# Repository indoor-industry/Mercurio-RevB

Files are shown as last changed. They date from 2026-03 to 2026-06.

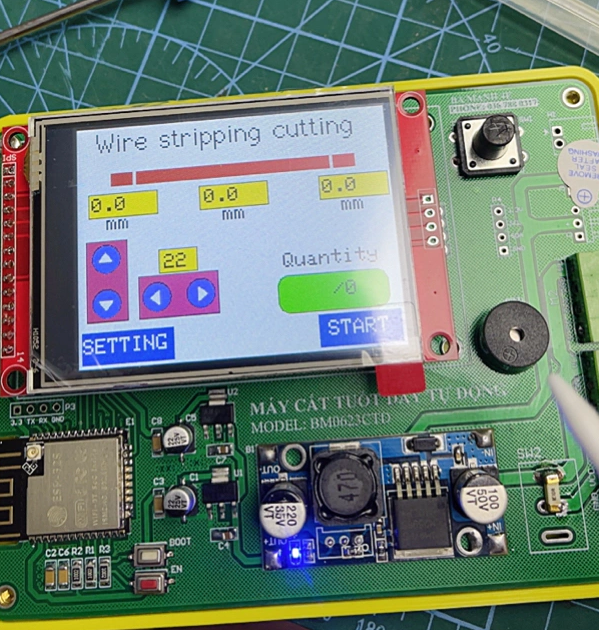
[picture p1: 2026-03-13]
Module/Case_10mm/tft-lcd-2-8-inch-ili9341-touch-320x240-1.snapshot.22/TFT LCD 2.8inch ILI9341 6.png

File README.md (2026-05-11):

Requires CDFER's KiCAD library (https://github.com/CDFER/JLCPCB-Kicad-Library) and the custom symbol and footprint libraries in Component models/KiCAD_symbol_ library. 

Contains version with bare ESP32-S3R8 chip and version with ESP32-WROOM-1 module. Only major difference is bare chip version features RTC clock and uses strapping pin GPIO46 for ILI9341 DC line. This should work but has to be tested.

## License

See the [LICENSE](LICENSE) file for details.

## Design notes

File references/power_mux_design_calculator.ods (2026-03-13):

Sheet: TPS2121
Inputs |  |  |  | Instructions:
VIN1 | 5 |  | V | Please edit green shaded cells to resemble your schematic
VIN2 | 3.7 |  | V | Grey shaded cells are automated outputs, please do not edit
R1 | 60000 | 60 | kΩ
R2 | 100000 | 100 | kΩ
R3 | 49900 | 49.9 | kΩ
R4 | 5000 | 5 | kΩ
RHYST | 10700 | 10.7 | kΩ
Overvoltage Inputs
R5 | 63400 | 63.4 | kΩ
R6 | 5000 | 5 | kΩ
R7 | 63400 | 63.4 | kΩ
R8 | 5000 | 5 | kΩ
Current Limit Inputs
RILM | 51100 | 51.1 | kΩ
Outputs
PR1 at VIN1 DC | 3.1250 |  | V
CP2 at VIN2 DC | 0.3370 |  | V |  | 0.27046783625731
IN1 at switchover | 0.5392 |  | V
Switchover using Hysteresis (N/A when not using RHYST)
PR1 R2 when IN2 selected using hysterisis | 9665.7633 |  | kΩ
PR1 when IN2 is selected using hysterisis | 0.0748 |  | V
IN1 voltage needed to switch back to IN1 when IN2 is selected using hysterisis | 2.4287 |  | V
Overvoltage
Vov1 | 14.5008 |  | V
Vov2 | 14.5008 |  | V
Current Limit
ILM | 2.20443450752477 |  | A

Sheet: TPS2116
Inputs |  |  |  | Instructions:
VIN1 | 5 |  | V | Please edit green shaded cells to resemble your schematic
VIN2 | 5 |  | V | Grey shaded cells are automated outputs, please do not edit
R1 | 9530 | 9.53 | kΩ
R2 | 5000 | 5 | kΩ
RHYST | 10000 | 10 | kΩ
Vref | 1 |  | V
Outputs
PR1 at VIN1 DC | 1.7206 |  | V
IN1 at switchover | 2.9060 |  | V
Switchover using Hysteresis (N/A when not using RHYST)
PR1 R2 when IN2 selected using hysterisis | 3333.3333 |  | kΩ
PR1 when IN2 selected using hysterisis | 0.7530 |  | V
IN1 voltage needed to switch back to IN1 when IN2 is selected using hysterisis | 3.8590 |  | V

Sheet: TPS2117
Inputs |  |  |  | Instructions:
VIN1 | 5 |  | V | Please edit green shaded cells to resemble your schematic
VIN2 | 5 |  | V | Grey shaded cells are automated outputs, please do not edit
R1 | 9530 | 9.53 | kΩ
R2 | 5000 | 5 | kΩ
RHYST | 10000 | 10 | kΩ
Vref | 1 |  | V
Outputs
PR1 at VIN1 DC | 1.7206 |  | V
IN1 at switchover | 2.9060 |  | V
Switchover using Hysteresis (N/A when not using RHYST)
PR1 R2 when IN2 selected using hysterisis | 3333.3333 |  | kΩ
PR1 when IN2 selected using hysterisis | 0.7530 |  | V
IN1 voltage needed to switch back to IN1 when IN2 is selected using hysterisis | 3.8590 |  | V

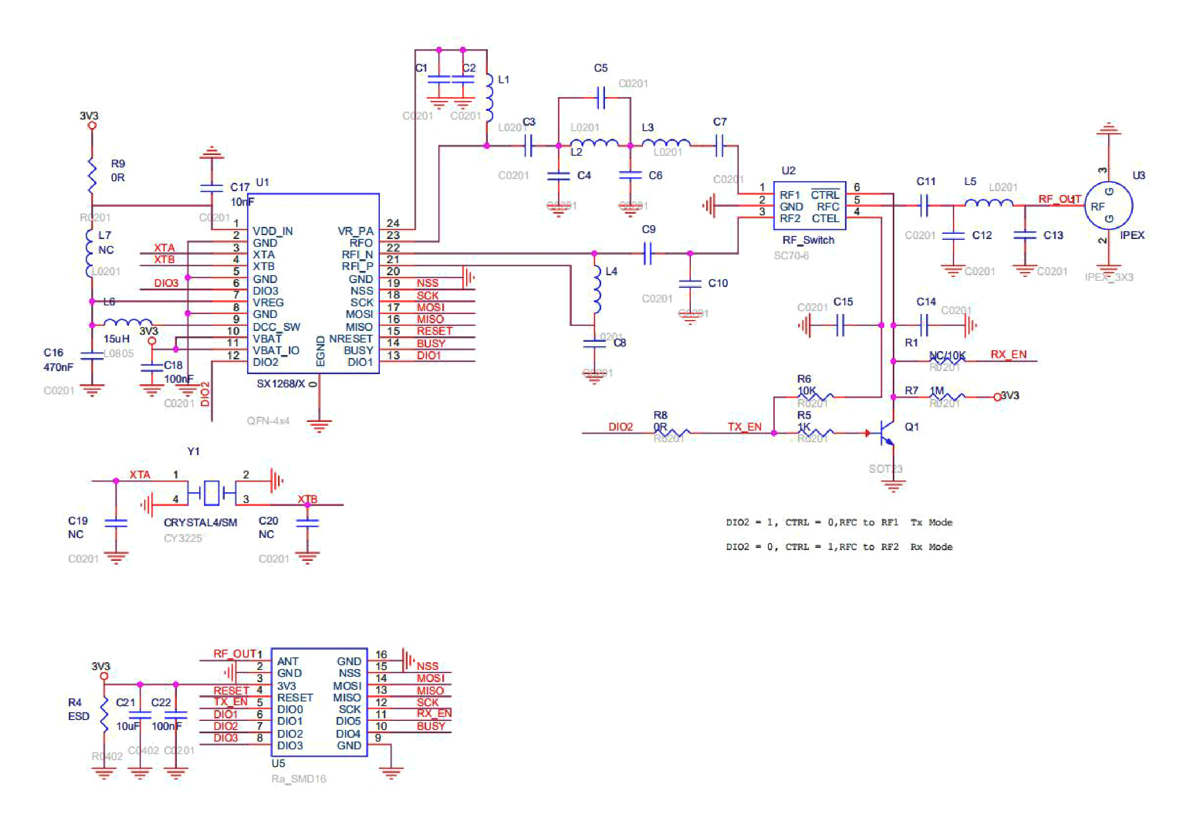
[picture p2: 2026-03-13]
references/Interfacing-RA-01-RA-02-SX1278-LoRa-Modules-with-ESP32-using-Arduino-Schematic-Diagram-CIRCUITSTATE-Electronics-01.png

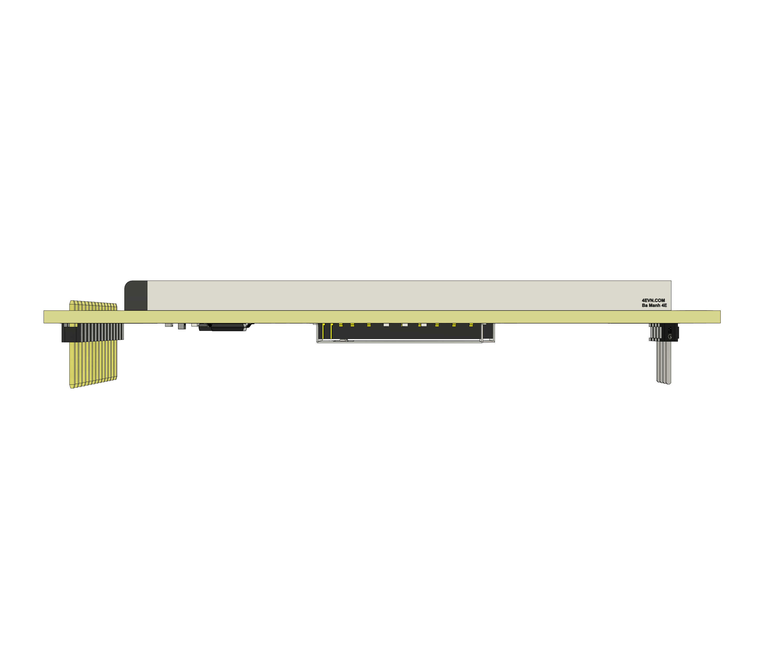
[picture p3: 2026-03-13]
Module/Case_10mm/tft-lcd-2-8-inch-ili9341-touch-320x240-1.snapshot.22/TFT LCD 2.8 inch ILI9341 4.png

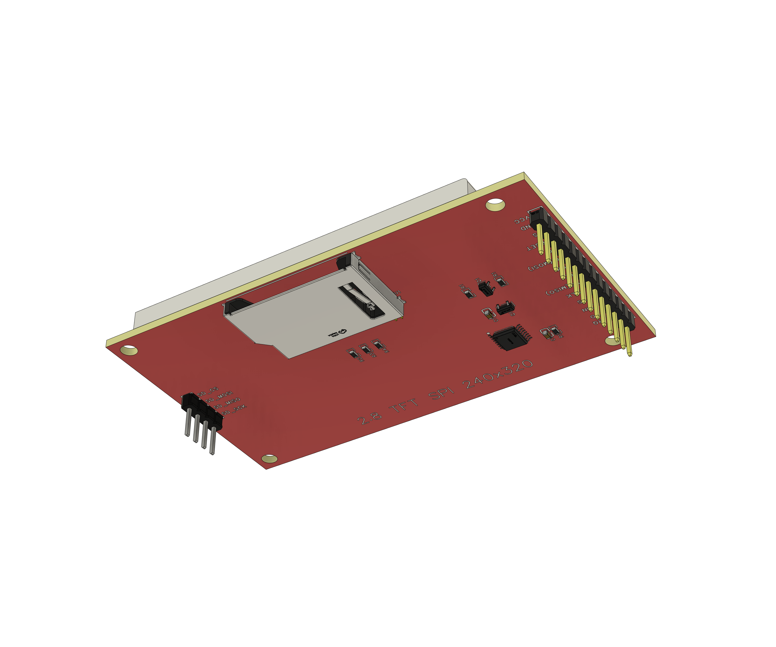
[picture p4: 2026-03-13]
Module/Case_9mm/tft-lcd-2-8-inch-ili9341-touch-320x240-1.snapshot.22/TFT LCD 2.8 inch ILI9341 3.png

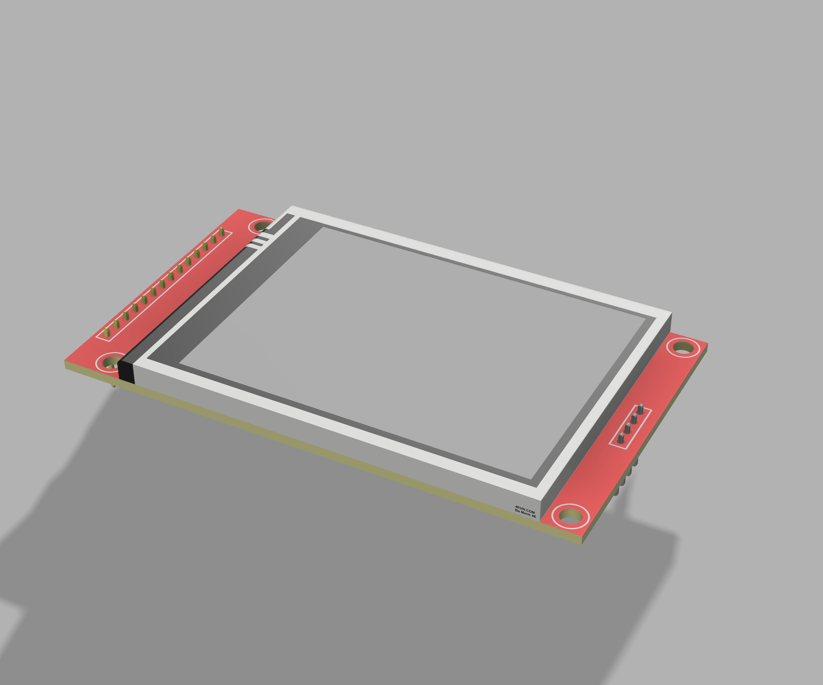
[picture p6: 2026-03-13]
Module/Case_10mm/tft-lcd-2-8-inch-ili9341-touch-320x240-1.snapshot.22/TFT LCD 2.8 inch ILI9341 5.png

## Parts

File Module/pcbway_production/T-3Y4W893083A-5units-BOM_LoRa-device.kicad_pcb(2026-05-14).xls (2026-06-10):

PCBWay Bom Quotation, Product No.:T-3Y4W893083A
Item # | *Designator | *Qty | Manufacturer | *Mfg Part # | Description / Value | Vendor Part # | *Package/Footprint | Mounting Type | Category | *Unit Price(5 units) | *Total | *Delivery Time | *Actual Purchase Mfg Part # | *PCBWay Note | Customer Reply | PCBWay Update
1 | C1 | 1 | Samsung Electro-Mechanics | CL10A225KO8NNNC | 2.2uF『 』16V 2.2uF X5R ±10% 0603 Multilayer Ceramic Capacitors MLCC - SMD/SMT ROHS『 』16V『 』±10%『 』2.2uF『 』X5R | C23630 | C_0603 | smt | Capacitors,Multilayer Ceramic Capacitors MLCC - SMD/SMT | $0.089 | $0.445
2 | C13, C20, C4, C47, C48, C7 | 6 | Samsung Electro-Mechanics | CL05A106MQ5NUNC | 10uF『 』6.3V 10uF X5R ±20% 0402 Multilayer Ceramic Capacitors MLCC - SMD/SMT ROHS『 』6.3V『 』±20%『 』10uF『 』X5R | C15525 | C_0402 | smt | Capacitors,Multilayer Ceramic Capacitors MLCC - SMD/SMT | $0.026 | $0.780
3 | C15, C16, C21, C23, C29, C30, C36, C39, C40, C46, C50, C52 | 12 | Samsung Electro-Mechanics | CL05B104KO5NNNC | 100nF『 』16V 100nF X7R ±10% 0402 Multilayer Ceramic Capacitors MLCC - SMD/SMT ROHS『 』16V『 』±10%『 』100nF『 』X7R | C1525 | C_0402 | smt | Capacitors,Multilayer Ceramic Capacitors MLCC - SMD/SMT | $0.047 | $2.820
4 | C19, C41, C42, C45, C5, C53, C57 | 7 | Samsung Electro-Mechanics | CL05A105KA5NQNC | 1uF『 』25V 1uF X5R ±10% 0402 Multilayer Ceramic Capacitors MLCC - SMD/SMT ROHS『 』25V『 』±10%『 』1uF『 』X5R | C52923 | C_0402 | smt | Capacitors,Multilayer Ceramic Capacitors MLCC - SMD/SMT | $0.015 | $0.525
5 | C2, C34, C37, C6 | 4 | Samsung Electro-Mechanics | CL10A106MA8NRNC | 10uF『 』25V 10uF X5R ±20% 0603 Multilayer Ceramic Capacitors MLCC - SMD/SMT ROHS『 』25V『 』±20%『 』10uF『 』X5R | C96446 | C_0603 | smt | Capacitors,Multilayer Ceramic Capacitors MLCC - SMD/SMT | $0.063 | $1.260
6 | C24, C9 | 2 | FH(Guangdong Fenghua Advanced Tech) | 0402CG330J500NT | 33pF『 』50V 33pF C0G ±5% 0402 Multilayer Ceramic Capacitors MLCC - SMD/SMT ROHS『 』50V『 』±5%『 』33pF『 』C0G | C1562 | C_0402 | smt | Capacitors,Multilayer Ceramic Capacitors MLCC - SMD/SMT | $0.016 | $0.160
7 | C27, C28 | 2 | FH(Guangdong Fenghua Advanced Tech) | 0402CG101J500NT | 100pF『 』50V 100pF C0G ±5% 0402 Multilayer Ceramic Capacitors MLCC - SMD/SMT ROHS『 』50V『 』±5%『 』100pF『 』C0G | C1546 | C_0402 | smt | Capacitors,Multilayer Ceramic Capacitors MLCC - SMD/SMT | $0.014 | $0.140
8 | C35 | 1 | FH(Guangdong Fenghua Advanced Tech) | 0402B102K500NT | 1nF『 』50V 1nF X7R ±10% 0402 Multilayer Ceramic Capacitors MLCC - SMD/SMT ROHS『 』50V『 』±10%『 』1nF『 』X7R | C1523 | C_0402 | smt | Capacitors,Multilayer Ceramic Capacitors MLCC - SMD/SMT | $0.033 | $0.165
9 | C43, C54 | 2 | Samsung Electro-Mechanics | CL05A475MP5NRNC | 4.7uF『 』10V 4.7uF X5R ±20% 0402 Multilayer Ceramic Capacitors MLCC - SMD/SMT ROHS『 』10V『 』±20%『 』4.7uF『 』X5R | C23733 | C_0402 | smt | Capacitors,Multilayer Ceramic Capacitors MLCC - SMD/SMT | $0.082 | $0.820
10 | C44 | 1 | FH(Guangdong Fenghua Advanced Tech) | 0402B221K500NT | 220pF『 』50V 220pF X7R ±10% 0402 Multilayer Ceramic Capacitors MLCC - SMD/SMT ROHS『 』50V『 』±10%『 』220pF『 』X7R | C1530 | C_0402 | smt | Capacitors,Multilayer Ceramic Capacitors MLCC - SMD/SMT | $0.028 | $0.140
11 | C51, C56 | 2 | Samsung Electro-Mechanics | CL10A226MQ8NRNC | 22uF『 』6.3V 22uF X5R ±20% 0603 Multilayer Ceramic Capacitors MLCC - SMD/SMT ROHS『 』6.3V『 』±20%『 』22uF『 』X5R | C59461 | C_0603 | smt | Capacitors,Multilayer Ceramic Capacitors MLCC - SMD/SMT | $0.052 | $0.520
12 | C8 | 1 | Samsung Electro-Mechanics | CL05B103KB5NNNC | 10nF『 』50V 10nF X7R ±10% 0402 Multilayer Ceramic Capacitors MLCC - SMD/SMT ROHS『 』50V『 』±10%『 』10nF『 』X7R | C15195 | C_0402 | smt | Capacitors,Multilayer Ceramic Capacitors MLCC - SMD/SMT | $0.040 | $0.200
13 | D2, D4, D5 | 3 |  | KT-0603R | LED『 』Light emitting diode | C2286 | LED_0603_1608Metric | smt |  | $0.058 | $0.870
14 | FLASH1, RESET1 | 2 | XUNPU | TS-1088-AR02016 | Tactile Button, 160gf『 』Without 50mA 4mm 100MΩ 100000 Times 12V 160gf 3mm 2mm Round Button Standing paste SPST SMD Tactile Switches ROHS | C720477 | SW_TS-1088-AR02016 | smt | Switches,Tactile Switches | $0.139 | $1.390
15 | J1 | 1 |  | TF-01A | Micro_SD_Card_Det1『 』Micro SD Card Socket with one card detection pin | C91145 | TF-SMD_TF-01A | smt |  | $0.179 | $0.895
16 | J2 | 1 |  | HC-TYPE-C-16P-3M2S | USB_C_Receptacle_USB2.0_14P『 』USB 2.0-only 14P Type-C Receptacle connector | C19274016 | USB_C_Receptacle_HCTL_HC-TYPE-C-16P-01A | smt |  | $0.182 | $0.910 |  |  | The quoted part number is [HC-TYPE-C-16P-3M2S], not [HC-TYPE-C-16P-01A] as specified in description | Correct, please refer to column “*Mfg Part #” and not to column “*Package/Footprint”
17 | J8 | 1 |  | BWU.FL-IPEX1 | U.FL『 』coaxial connector (BNC, SMA, SMB, SMC, Cinch/RCA, LEMO, ...) | C5137195 | IPEX-SMD_BWIPX-1-001E | smt |  | $0.104 | $0.520 |  |  | The quoted part number is [BWU.FL-IPEX1], not [BWIPX-1-001E] as specified in description | Correct, please refer to column “*Mfg Part #” and not to column “*Package/Footprint”
18 | L2 | 1 |  | SDCL1005C68NJTDF | 68nH『 』Inductor | C32836 | L_0402 | smt |  | $0.055 | $0.275
19 | R1, R33, R7 | 3 | UNI-ROYAL(Uniroyal Elec) | 0402WGF1003TCE | 100kΩ『 』62.5mW Thick Film Resistors 50V ±100ppm/°C ±1% 100kΩ 0402 Chip Resistor - Surface Mount ROHS『 』±1%『 』±100ppm/°C | C25741 | R_0402 | tht | Resistors,Chip Resistor - Surface Mount | $0.015 | $0.225
20 | R10, R30, R50, R54, R8 | 5 | UNI-ROYAL(Uniroyal Elec) | 0402WGF0000TCE | 0Ω『 』62.5mW Thick Film Resistors 50V ±800ppm/°C ±1% 0Ω 0402 Chip Resistor - Surface Mount ROHS『 』±1%『 』±800ppm/°C | C17168 | R_0402 | tht | Resistors,Chip Resistor - Surface Mount | $0.004 | $0.100
21 | R11, R14, R16, R17, R22, R25, R31, R37, R4, R41, R49, R52, R53, R61, R62, R63, R72 | 17 | UNI-ROYAL(Uniroyal Elec) | 0402WGF1002TCE | 10kΩ『 』62.5mW Thick Film Resistors 50V ±100ppm/°C ±1% 10kΩ 0402 Chip Resistor - Surface Mount ROHS『 』±1%『 』±100ppm/°C | C25744 | R_0402 | tht | Resistors,Chip Resistor - Surface Mount | $0.001 | $0.085
22 | R12 | 1 | UNI-ROYAL(Uniroyal Elec) | 0402WGF4700TCE | 470Ω『 』62.5mW Thick Film Resistors 50V ±100ppm/°C ±1% 470Ω 0402 Chip Resistor - Surface Mount ROHS『 』±1%『 』±100ppm/°C | C25117 | R_0402 | tht | Resistors,Chip Resistor - Surface Mount | $0.020 | $0.100
23 | R13, R42 | 2 | UNI-ROYAL(Uniroyal Elec) | 0402WGF5101TCE | 5.1kΩ『 』62.5mW Thick Film Resistors 50V ±100ppm/°C ±1% 5.1kΩ 0402 Chip Resistor - Surface Mount ROHS『 』±1%『 』±100ppm/°C | C25905 | R_0402 | tht | Resistors,Chip Resistor - Surface Mount | $0.011 | $0.110
24 | R15, R20, R34, R35, R43, R44, R45, R46, R5, R55, R56, R57, R58, R59, R60, R64, R65 | 17 | UNI-ROYAL(Uniroyal Elec) | 0402WGF330JTCE | 33Ω『 』62.5mW Thick Film Resistors 50V ±100ppm/°C ±1% 33Ω 0402 Chip Resistor - Surface Mount ROHS『 』±1%『 』±100ppm/°C | C25105 | R_0402 | tht | Resistors,Chip Resistor - Surface Mount | $0.001 | $0.085
25 | R18, R2 | 2 | UNI-ROYAL(Uniroyal Elec) | 0402WGF1001TCE | 1kΩ『 』62.5mW Thick Film Resistors 50V ±100ppm/°C ±1% 1kΩ 0402 Chip Resistor - Surface Mount ROHS『 』±1%『 』±100ppm/°C | C11702 | R_0402 | tht | Resistors,Chip Resistor - Surface Mount | $0.019 | $0.190
26 | R23, R40 | 2 | UNI-ROYAL(Uniroyal Elec) | 0402WGF4702TCE | 47kΩ『 』62.5mW Thick Film Resistors 50V ±100ppm/°C ±1% 47kΩ 0402 Chip Resistor - Surface Mount ROHS『 』±1%『 』±100ppm/°C | C25792 | R_0402 | tht | Resistors,Chip Resistor - Surface Mount | $0.019 | $0.190
27 | R32 | 1 | UNI-ROYAL(Uniroyal Elec) | 0402WGF5100TCE | 510Ω『 』62.5mW Thick Film Resistors 50V ±100ppm/°C ±1% 510Ω 0402 Chip Resistor - Surface Mount ROHS『 』±1%『 』±100ppm/°C | C25123 | R_0402 | tht | Resistors,Chip Resistor - Surface Mount | $0.032 | $0.160
28 | R38 | 1 | UNI-ROYAL(Uniroyal Elec) | 0402WGF2202TCE | 22kΩ『 』62.5mW Thick Film Resistors 50V ±100ppm/°C ±1% 22kΩ 0402 Chip Resistor - Surface Mount ROHS『 』±1%『 』±100ppm/°C | C25768 | R_0402 | tht | Resistors,Chip Resistor - Surface Mount | $0.024 | $0.120
29 | R47, R48 | 2 | UNI-ROYAL(Uniroyal Elec) | 0402WGF2201TCE | 2.2kΩ『 』62.5mW Thick Film Resistors 50V ±100ppm/°C ±1% 2.2kΩ 0402 Chip Resistor - Surface Mount ROHS『 』±1%『 』±100ppm/°C | C25879 | R_0402 | tht | Resistors,Chip Resistor - Surface Mount | $0.010 | $0.100
30 | R51 | 1 | UNI-ROYAL(Uniroyal Elec) | 0603WAF1302T5E | 13kΩ『 』100mW Thick Film Resistors 75V ±100ppm/°C ±1% 13kΩ 0603 Chip Resistor - Surface Mount ROHS『 』±1%『 』±100ppm/°C | C22797 | R_0603 | smt | Resistors,Chip Resistor - Surface Mount | $0.035 | $0.175
31 | R70, R71 | 2 | UNI-ROYAL(Uniroyal Elec) | 0402WGF1000TCE | 100Ω『 』62.5mW Thick Film Resistors 50V ±1% ±200ppm/°C 100Ω 0402 Chip Resistor - Surface Mount ROHS『 』±1%『 』±200ppm/°C | C25076 | R_0402 | tht | Resistors,Chip Resistor - Surface Mount | $0.012 | $0.120
32 | SW1, SW2 | 2 |  | EVQPUC02K | EVQPUC02K | C79174 | SW-SMD_EVQPUD02K | smt |  | $0.342 | $3.420 |  |  | The quoted part number is [EVQPUC02K], not [EVQPUD02K] as specified in description | Correct, please refer to column “*Mfg Part #” and not to column “*Package/Footprint”
33 | U10 | 1 | Torex Semicon | XC6206P332MR-G | XC6206P332MR『 』200mA Fixed 3.3V Positive electrode 6V SOT-23-3L Voltage Regulators - Linear, Low Drop Out (LDO) Regulators ROHS | C5446 | SOT-23-3_L2.9-W1.6-P1.90-LS2.8-BR | smt | Power Management ICs,Linear Voltage Regulators (LDO) | $0.291 | $1.455
34 | U12 | 1 |  | TLV62569DBVR | TLV62569DBV『 』High Efficiency Synchronous Buck Converter, Adjustable Output 0.6V-5.5V, 2A, SOT-23-5 | C141836 | SOT-23-5 | smt |  | $0.513 | $2.565 | 7-10 Workdays
35 | U14 | 1 |  | MCP23017T-E/ML | MCP23017_ML『 』16-bit I/O expander, I2C, interrupts, w pull-ups, GPA/B7 output only (https://microchip.my.site.com/s/article/GPA7---GPB7-Cannot-Be-Used-as-Inputs-In-MCP23017), QFN-28 | C629439 | QFN-28-1EP_6x6mm_P0.65mm_EP4.25x4.25mm | smt |  | $2.561 | $12.805
36 | U17 | 1 |  | Ra-01SH-P | RA-01SH-P | C42420049 | COMM-SMD_17P-L17.0-W16.0-P2.00_RA-01S-P | smt |  | $7.516 | $37.580
37 | U18 | 1 |  | L76KB-A58 | L76KB-A58 | C2916234 | GPSM-SMD_18P-L10.1-W9.7-P1.10 | smt |  | $5.735 | $28.675
38 | U19 | 1 |  | MAX98357AETE+T | MAX98357A『 』Mono DAC with amplifier, I2S, PCM, TDM, 32-bit, 96khz, 3.2W, TQFP-16 | C910544 | TQFN-16-1EP_3x3mm_P0.5mm_EP1.23x1.23mm | smt |  | $1.449 | $7.245
39 | U3 | 1 |  | ICS-43432 | ICS-43432 | C574021 | SENSOR-SMD_ICS-43432 | smt |  | $4.971 | $24.855 | 7-10 Workdays
40 | U4 | 1 |  | ESP32-S3-WROOM-1(N16R8) | ESP32-S3-WROOM-1(N16R8) | C2913202 | WIRELM-SMD_ESP32-S3-WROOM-1 | smt |  | $4.226 | $21.130 |  | ESP32-S3-WROOM-1-N16R8 |  | Correct, that seems like a matter of formatting
41 | U5 | 1 |  | SK-12D02-VG5 | SK-12D02-VG5 | C136722 | SW-TH_SK-12D02-VG5 | tht |  | $0.201 | $1.005
42 | U6 | 1 |  | USBLC6-2P6 | USBLC6-2P6『 』Very low capacitance ESD protection diode, 2 data-line, SOT-666 | C15999 | SOT-666 | smt |  | $0.212 | $1.060
43 | U7 | 1 |  | BQ25185DLHR | BQ25185DLHR | C19725033 | WSON-10_L2.2-W2.0-P0.40-BL-EP_TI_DLH0010A | smt |  | $2.325 | $11.625
44 | U8 | 1 |  | TPS22917LDBVR | TPS22917LDBV『 』1V to 5.5V, 2A, 80mΩ Ultra-Low Leakage Load Switch, Active Low, SOT23-6 | C3235537 | SOT-23-6 | smt |  | $0.560 | $2.800
45 | U9 | 1 |  | MHCI04020-2R2M-R8 | MHCI04020-2R2M-R8 | C142096 | IND-SMD_L4.6-W4.1 | smt |  | $0.280 | $1.400
 |  |  |  |  |  |  |  |  |  | Component Cost | $172.22
 |  |  |  |  |  |  |  |  |  | Assembly Cost
 |  |  |  |  |  |  |  |  |  | PCB Cost
 |  |  |  |  |  |  |  |  |  | V0 Member 0% off | $0.00
 |  |  |  |  |  |  |  |  |  | All Total 5 Units | $172.22

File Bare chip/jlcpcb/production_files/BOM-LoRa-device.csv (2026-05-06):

Comment | Designator | Footprint | LCSC | Quantity
0Ω | R10,R21,R26,R27,R28,R29,R30,R50,R54,R55,R56,R57,R58,R59,R6,R60,R65,R8,R9 | R_0402 | C17168 | 19
1.4pF | C12,C31 | C_0402 | C2181496 | 2
100kΩ | R1,R33,R7 | R_0402 | C25741 | 3
100nF | C10,C15,C16,C18,C21,C23,C29,C3,C30,C32,C33,C36,C39,C40,C46 | C_0402 | C1525 | 15
100pF | C27,C28 | C_0402 | C1546 | 2
100Ω | R24,R36 | R_0402 | C25076 | 2
10kΩ | R11,R14,R16,R17,R22,R25,R3,R31,R37,R39,R4,R41,R49,R52,R53,R61,R62,R63,R67 | R_0402 | C25744 | 19
10nF | C8 | C_0402 | C15195 | 1
10uF | C11,C13,C20,C4,C47,C48,C7 | C_0402 | C15525 | 7
10uF | C55 | C_0603 | C19702 | 1
10uF | C2,C34,C6 | C_0603 | C96446 | 3
12pF | C22,C37,C38,C49 | C_0402 | C1547 | 4
13kΩ | R51 | R_0603 | C22797 | 1
1kΩ | R18,R2 | R_0402 | C11702 | 2
1nF | C35 | C_0402 | C1523 | 1
1uF | C17,C19,C25,C26,C41,C42,C45,C5,C53 | C_0402 | C52923 | 9
2.2kΩ | R47,R48 | R_0402 | C25879 | 2
2.2uF | C1 | C_0603 | C23630 | 1
2.7nH | L6 | L_0402 | C27123 | 1
220pF | C44 | C_0402 | C1530 | 1
22kΩ | R38 | R_0402 | C25768 | 1
22uF | C56 | C_0603 | C59461 | 1
24nH | L4 | L_0402 | C74301 | 1
2nH | L3 | L_0402 | C18216 | 1
32.768 kHz | Y1 | Crystal_SMD_3215-2Pin_3.2x1.5mm | C32346 | 1
33pF | C24,C9 | C_0402 | C1562 | 2
33Ω | R15,R20,R34,R35,R43,R44,R45,R46,R5 | R_0402 | C25105 | 9
4.7uF | C43,C54 | C_0402 | C23733 | 2
40MHz(10ppm) | Y2 | Crystal_SMD_2520-4Pin_2.5x2.0mm | C5261125 | 1
470Ω | R12,R19 | R_0402 | C25117 | 2
47kΩ | R23,R40 | R_0402 | C25792 | 2
5.1kΩ | R13,R42 | R_0402 | C25905 | 2
510Ω | R32 | R_0402 | C25123 | 1
68nH | L2 | L_0402 | C32836 | 1
BQ25185DLHR | U7 | WSON-10_L2.2-W2.0-P0.40-BL-EP_TI_DLH0010A | C19725033 | 1
ESP32-S3 | U1 | QFN-56-1EP_7x7mm_P0.4mm_EP4x4mm | C2913194 | 1
EVQPUC02K | SW1,SW2 | SW-SMD_EVQPUD02K | C79174 | 2
ICS-43432 | U3 | SENSOR-SMD_ICS-43432 | C574021 | 1
L76KB-A58 | U18 | GPSM-SMD_18P-L10.1-W9.7-P1.10 | C2916234 | 1
LED | D2,D3,D4,D5 | LED_0603_1608Metric | C2286 | 4
MAX98357A | U19 | TQFN-16-1EP_3x3mm_P0.5mm_EP1.23x1.23mm | C910544 | 1
MC-121-L119 | U11 | USB-C-SMD_HANBO_MC-121-L119 | C6332278 | 1
MCP23017_ML | U14 | QFN-28-1EP_6x6mm_P0.65mm_EP4.25x4.25mm | C629439 | 1
MHCI04020-2R2M-R8 | U9 | IND-SMD_L4.6-W4.1 | C142096 | 1
Micro_SD_Card_Det1 | J1 | TF-SMD_TF-01A | C91145 | 1
RA-01SH-P | U17 | COMM-SMD_17P-L17.0-W16.0-P2.00_RA-01S-P | C42420049 | 1
SK-12D02-VG5 | U5 | SW-TH_SK-12D02-VG5 | C136722 | 1
TLV62569DBV | U12 | SOT-23-5 | C141836 | 1
TPS22917LDBV | U8 | SOT-23-6 | C3235537 | 1
Tactile Button, 160gf | FLASH1,RESET1 | SW_TS-1088-AR02016 | C720477 | 2
U.FL | J8 | IPEX-SMD_BWIPX-1-001E | C5137195 | 1
USBLC6-2P6 | U6 | SOT-666 | C15999 | 1
W25Q128JVS | U2 | SOIC-8_5.3x5.3mm_P1.27mm | C97521 | 1
XC6206P332MR | U10 | SOT-23-3_L2.9-W1.6-P1.90-LS2.8-BR | C5446 | 1
Conn_01x14_Pin | J4 | PinSocket_1x14_P2.54mm_Vertical |  | 1
Conn_01x04_Pin | J3 | PinSocket_1x04_P2.54mm_Vertical |  | 1
Conn_01x04_Pin | J6 | PinSocket_1x04_P2.54mm_Vertical |  | 1
Antenna | AE1 | Texas_SWRA117D_2.4GHz_Left |  | 1
DNP |  | C_0402 |  | 0
~ |  | C_0402 |  | 0
DNP |  | L_0402 |  | 0
~ |  | C_0402 |  | 0
~ |  | C_0402 |  | 0
~ |  | C_0402 |  | 0
TestPoint | TP1 | TestPoint_Loop_D1.80mm_Drill1.0mm_Beaded |  | 1

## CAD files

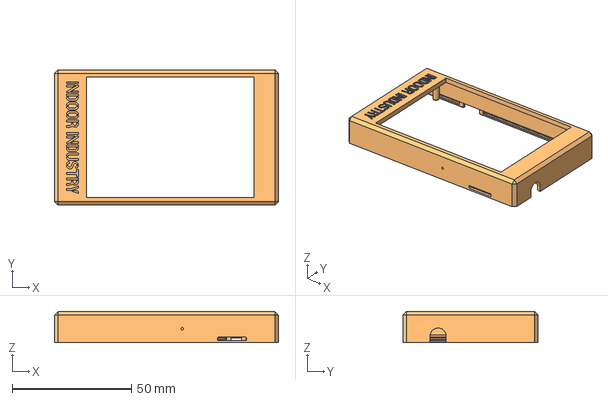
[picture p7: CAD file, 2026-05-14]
Module/Case_10mm/LoRa-device-Lid.step
94.0 x 56.8 x 13.0 mm

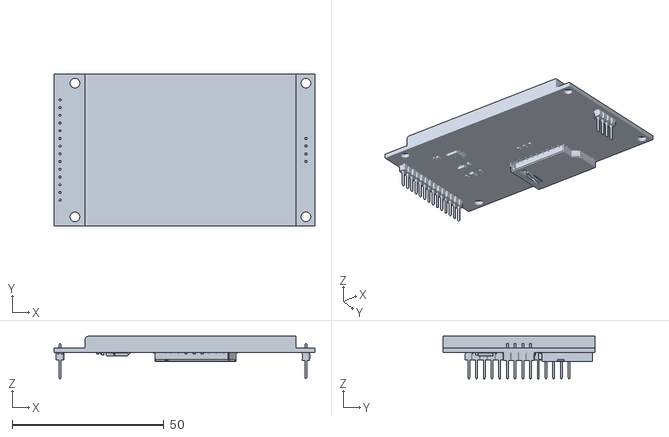
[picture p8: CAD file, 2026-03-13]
Module/Case_10mm/tft-lcd-2-8-inch-ili9341-touch-320x240-1.snapshot.22/TFT LCD 2.8 inch ILI9341.stl
86.0 x 50.0 x 14.0

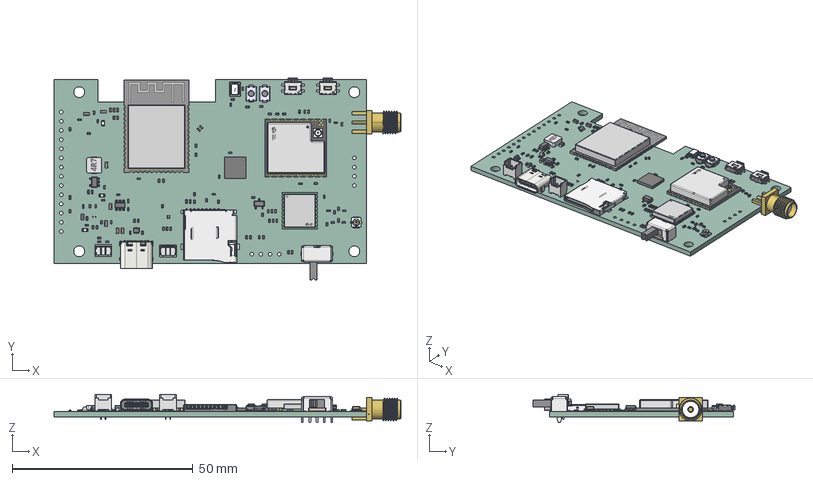
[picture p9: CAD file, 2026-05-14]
Module/Case_9mm/LoRa-device.step
96.0 x 55.8 x 7.85 mm
R_0402_1005Metric x 55
LED_0603_1608Metric x 3
C_0402_1005Metric x 38
SOT-23-5
L_0402_1005Metric
CONN-TH_1.25T-1-2A x 2
TS-1088-AR02016 x 2
SOT_666
SMA-TH_5P-L6.5-W6.5-H9.5_BWSMA-KE-P001
C_0603_1608Metric x 7
IND-SMD_L4.6-W4.1-H1.5
SOT-23-3L_L2.9-W1.6-H1.1-LS2.8-P0.95
SOT-23-6
R_0603_1608Metric
IPEX-SMD_BWIPX-1-001E
USB_C_Receptacle_16P_TopMnt_Horizontal_GCT_USB4105-xx-A
QFN-28-1EP_6x6mm_Pitch0.65mm
SW-SMD_EVQPUC02K-L4.5-W4.7-H1.7-P5.25-LS6.4 x 2
WIRELM-SMD_ESP32-S3-WROOM-1
GPSM-SMD_18P-L10.1-W9.7-P1.10
TF-SMD_TF-01A
SENSOR-SMD_ICS-43432
COMM-SMD_17P-L17.0-W16.0-P2.00_RA-01S-P
LoRa-device_PCB

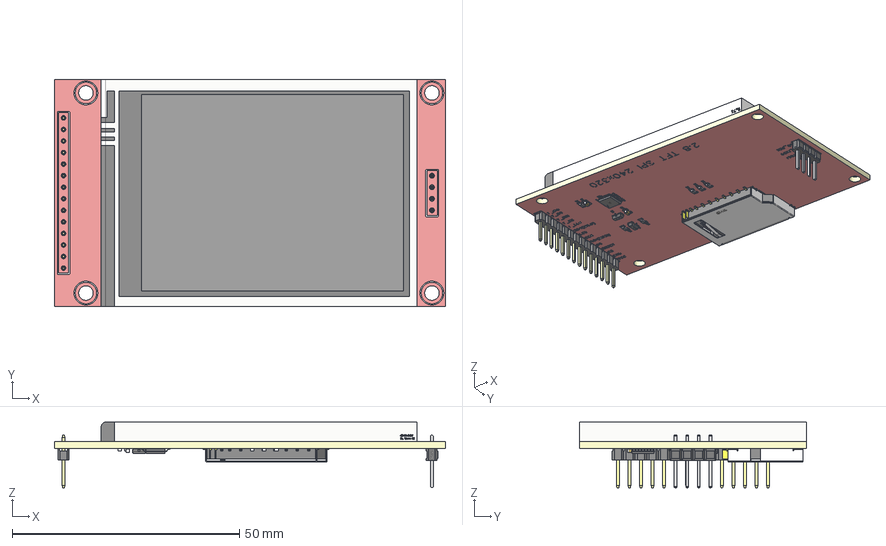
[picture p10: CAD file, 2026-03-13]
Module/Case_10mm/tft-lcd-2-8-inch-ili9341-touch-320x240-1.snapshot.22/TFT LCD 2.8 inch ILI9341 touch.step
86.0 x 50.0 x 14.5 mm
Board~s9RP
TopSilkscreen~s9RP
BottomSilkscreen~s9RP
HDR-TH_4P-P2.54-V-M~HDR-TH_4P-P2.54-M-LI-1X4P~s9RP
R0603~R0603~s9RP x 6
C0603~C0603_L1.6-W0.8-H0.8~s9RP x 2
CONN-TH_PZ254V-11-14P~CONN-TH_PZ254V-11-14P~s9RP
SD-CARD-SMD_SD-CARD-11P~SD-CARD-SMD_SD-CARD-11P~s9RP
TSSOP-16_L5.0-W4.4-P0.65-LS6.4-BL~TSSOP-16_L5.0-W4.4-H1.0-LS6.4-P0.65 ~s9RP
SOT-23-3_L2.9-W1.3-P1.90-LS2.4-BR~SOT-23-3P_L2.9-W1.3-H1.0-LS2.4-P0.9 5~s9RP x 2

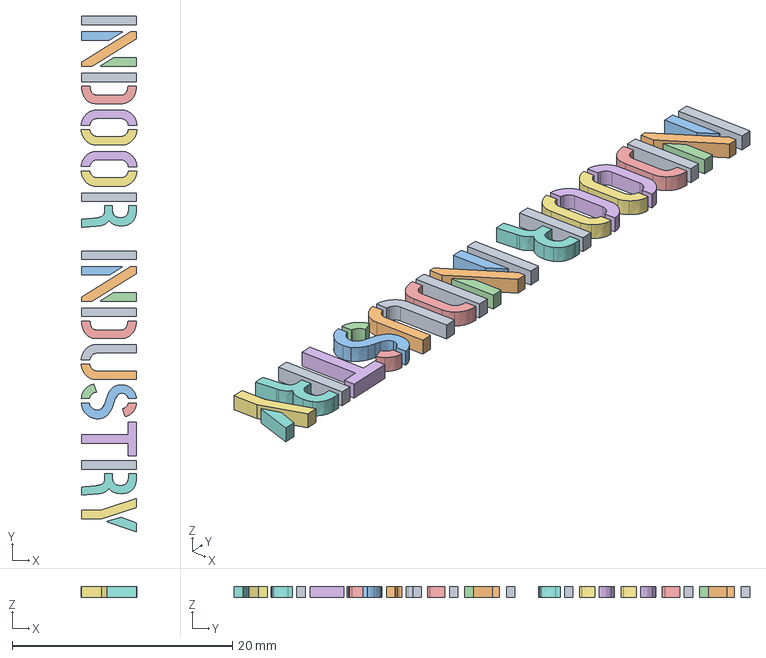
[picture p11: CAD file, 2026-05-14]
Module/Case_10mm/LoRa-device-Text.step
5.07 x 46.8 x 1.00 mm

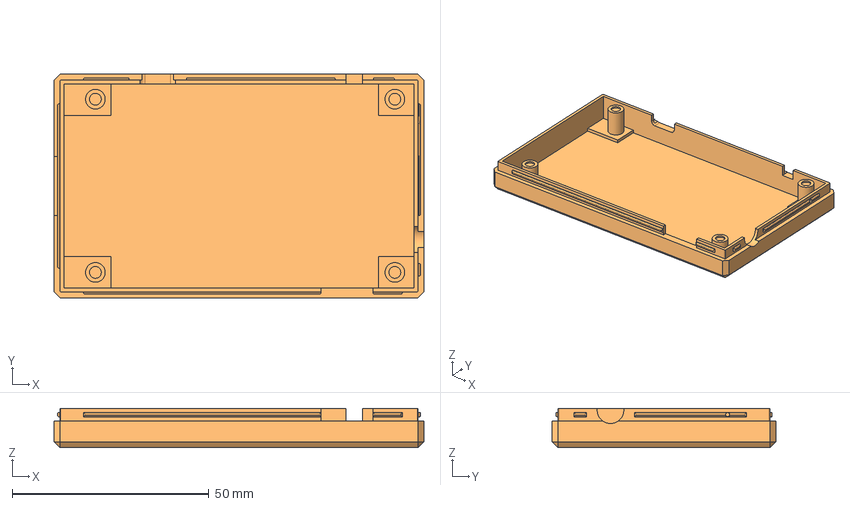
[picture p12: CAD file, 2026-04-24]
Module/Case_9mm/LoRa-device-Bottom.step
94.0 x 56.8 x 10.0 mm

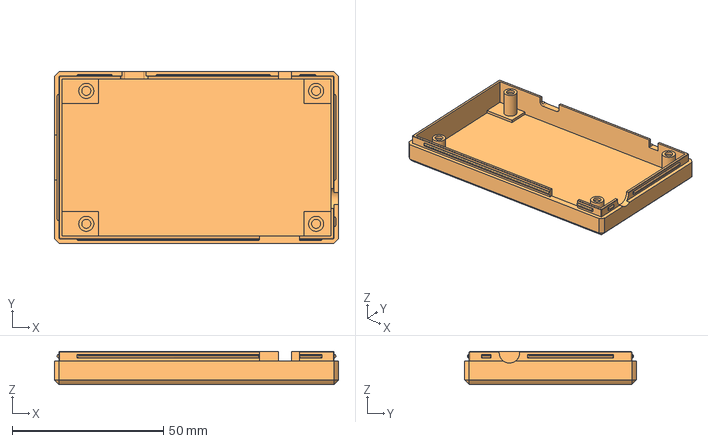
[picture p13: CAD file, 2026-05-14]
Module/Case_10mm/LoRa-device-Bottom.step
94.0 x 56.8 x 11.0 mm

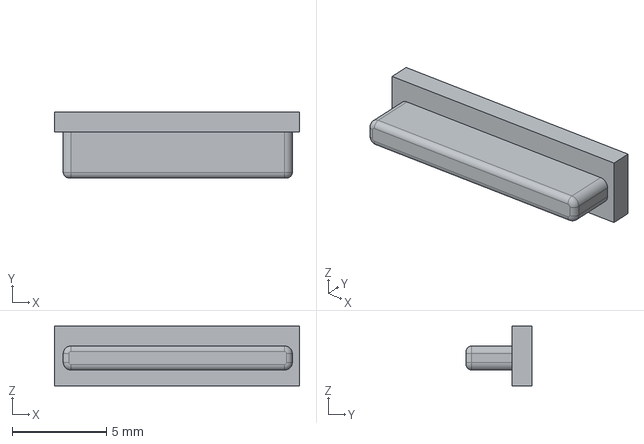
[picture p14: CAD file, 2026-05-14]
Module/Case_10mm/LoRa-device-Buttons.step
13.0 x 3.50 x 3.17 mm

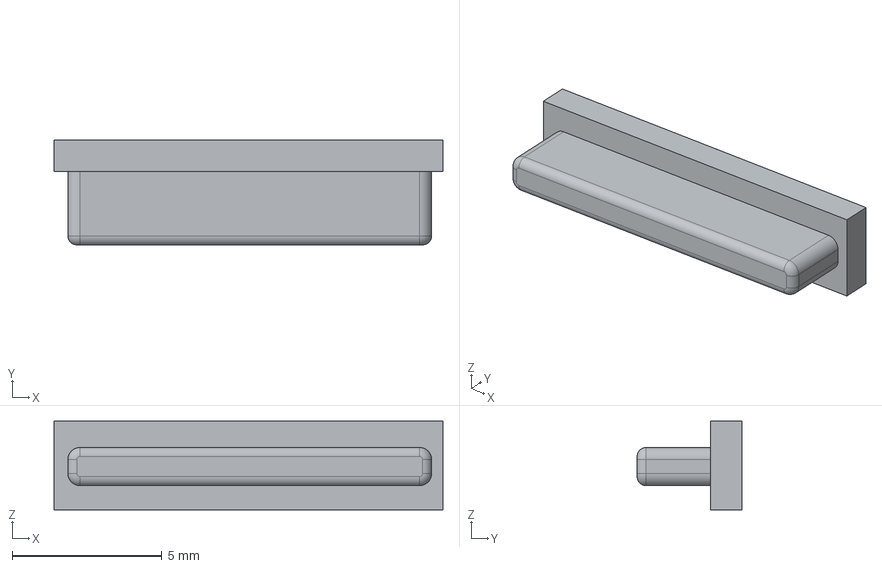
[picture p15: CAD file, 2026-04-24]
Module/Case_9mm/LoRa-device-Buttons.step
13.0 x 3.50 x 2.97 mm

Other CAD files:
Module/Case_9mm/LoRa-device-Lid.step
Module/Case_9mm/LoRa-device-Text.step
Module/Case_10mm/LoRa-device.FCStd
Module/Case_9mm/LoRa-device.FCStd

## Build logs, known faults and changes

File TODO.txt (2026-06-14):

If everything else works:

Add module to BOM and have it assembled
Consider changing MEMS mic depending on performance
Change external I2C pin header with JST connector (SM04B-SRSS-TB(LF)(SN) LCSC: C160404)
Not necessary, but could swap positive and negative in both battery and audio out connectors, matches what I have
GPS antenna silkscreen text is in wrong position
Amplifier Jumper can probably just be fixed to GND (+12dB)

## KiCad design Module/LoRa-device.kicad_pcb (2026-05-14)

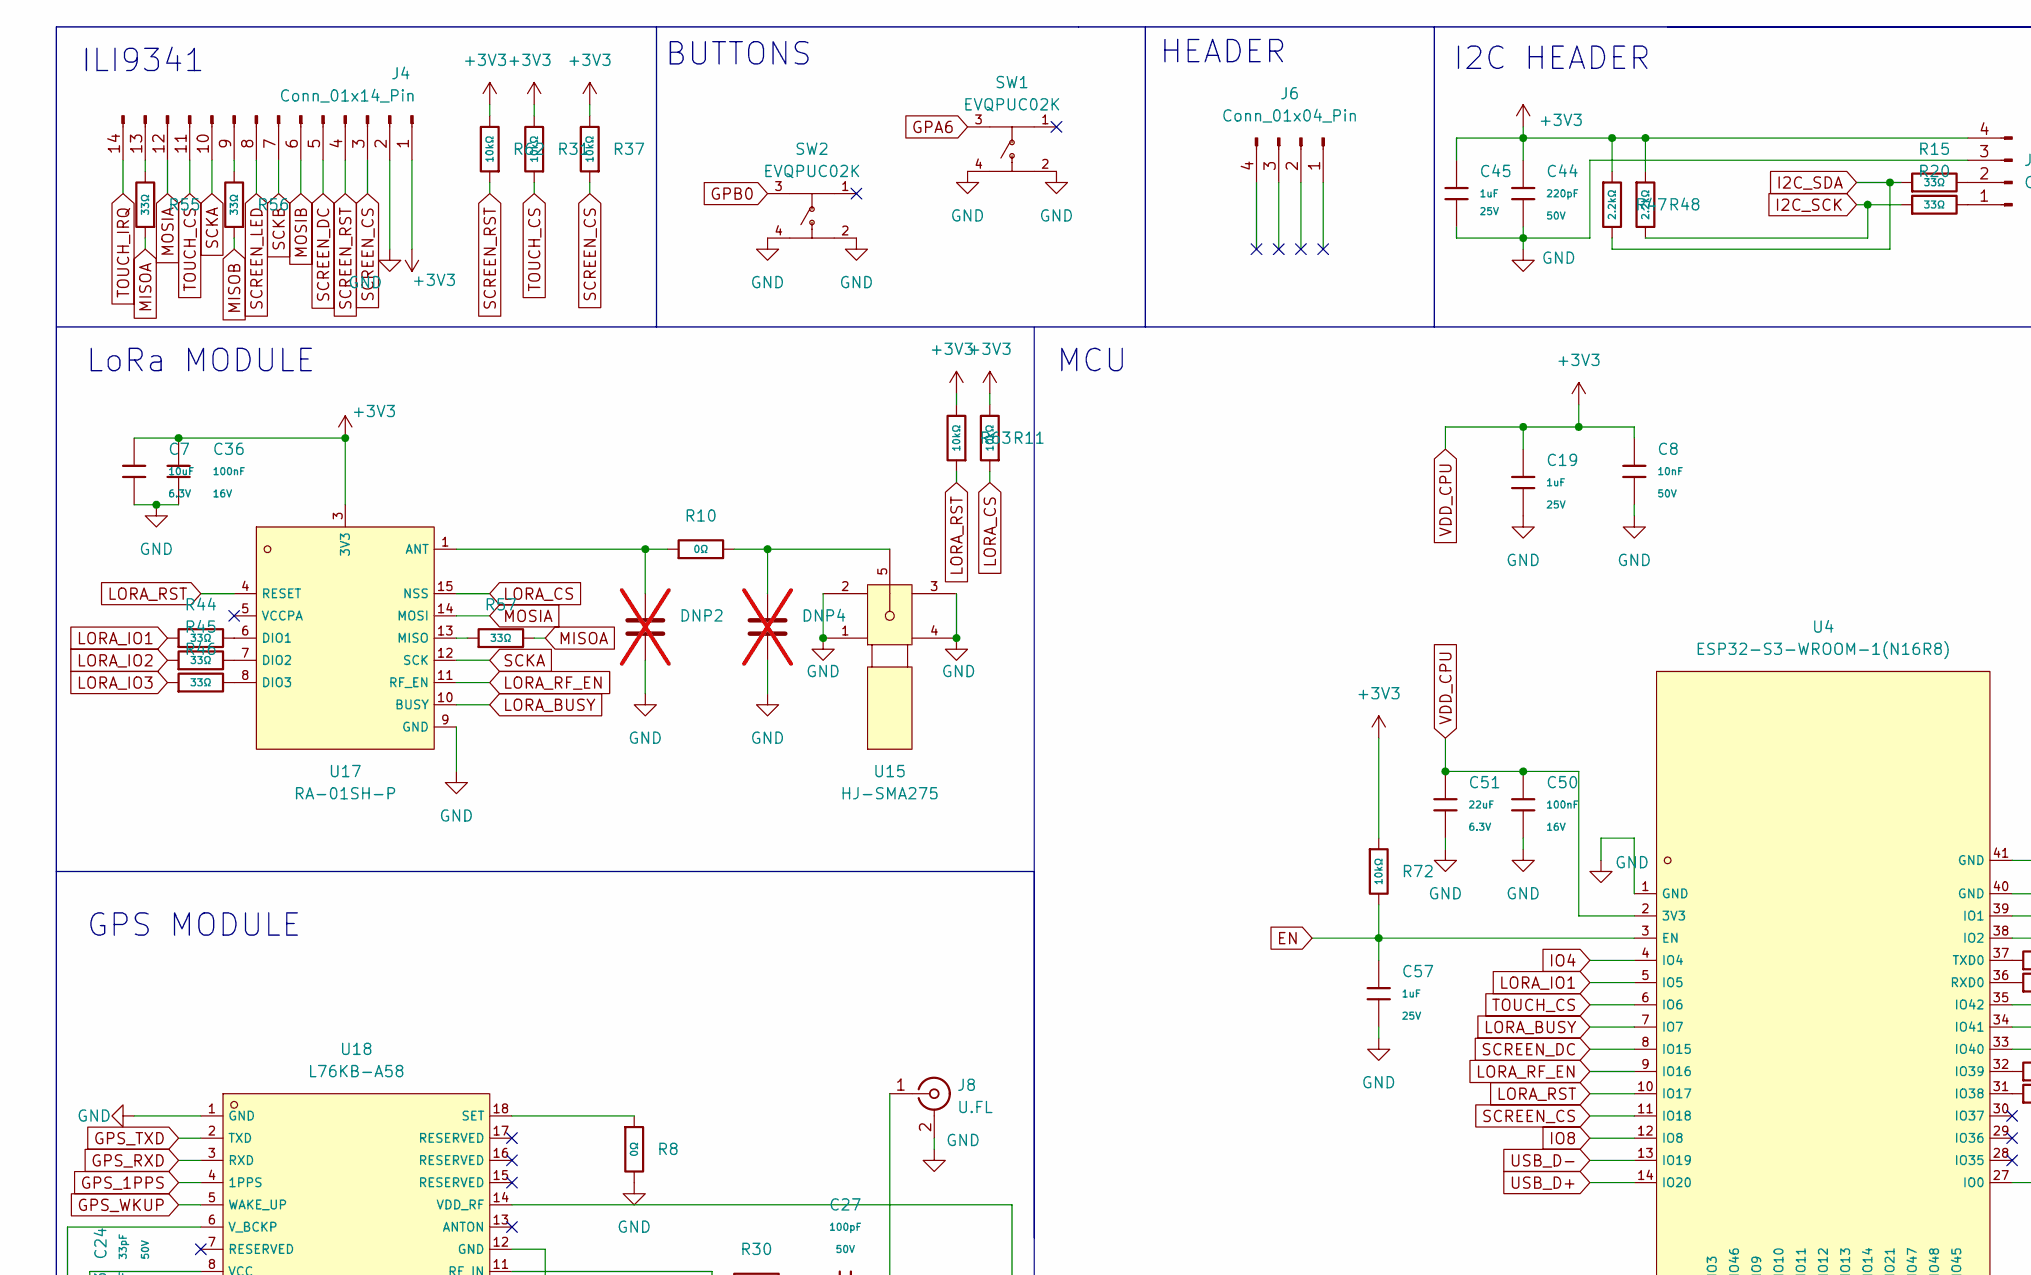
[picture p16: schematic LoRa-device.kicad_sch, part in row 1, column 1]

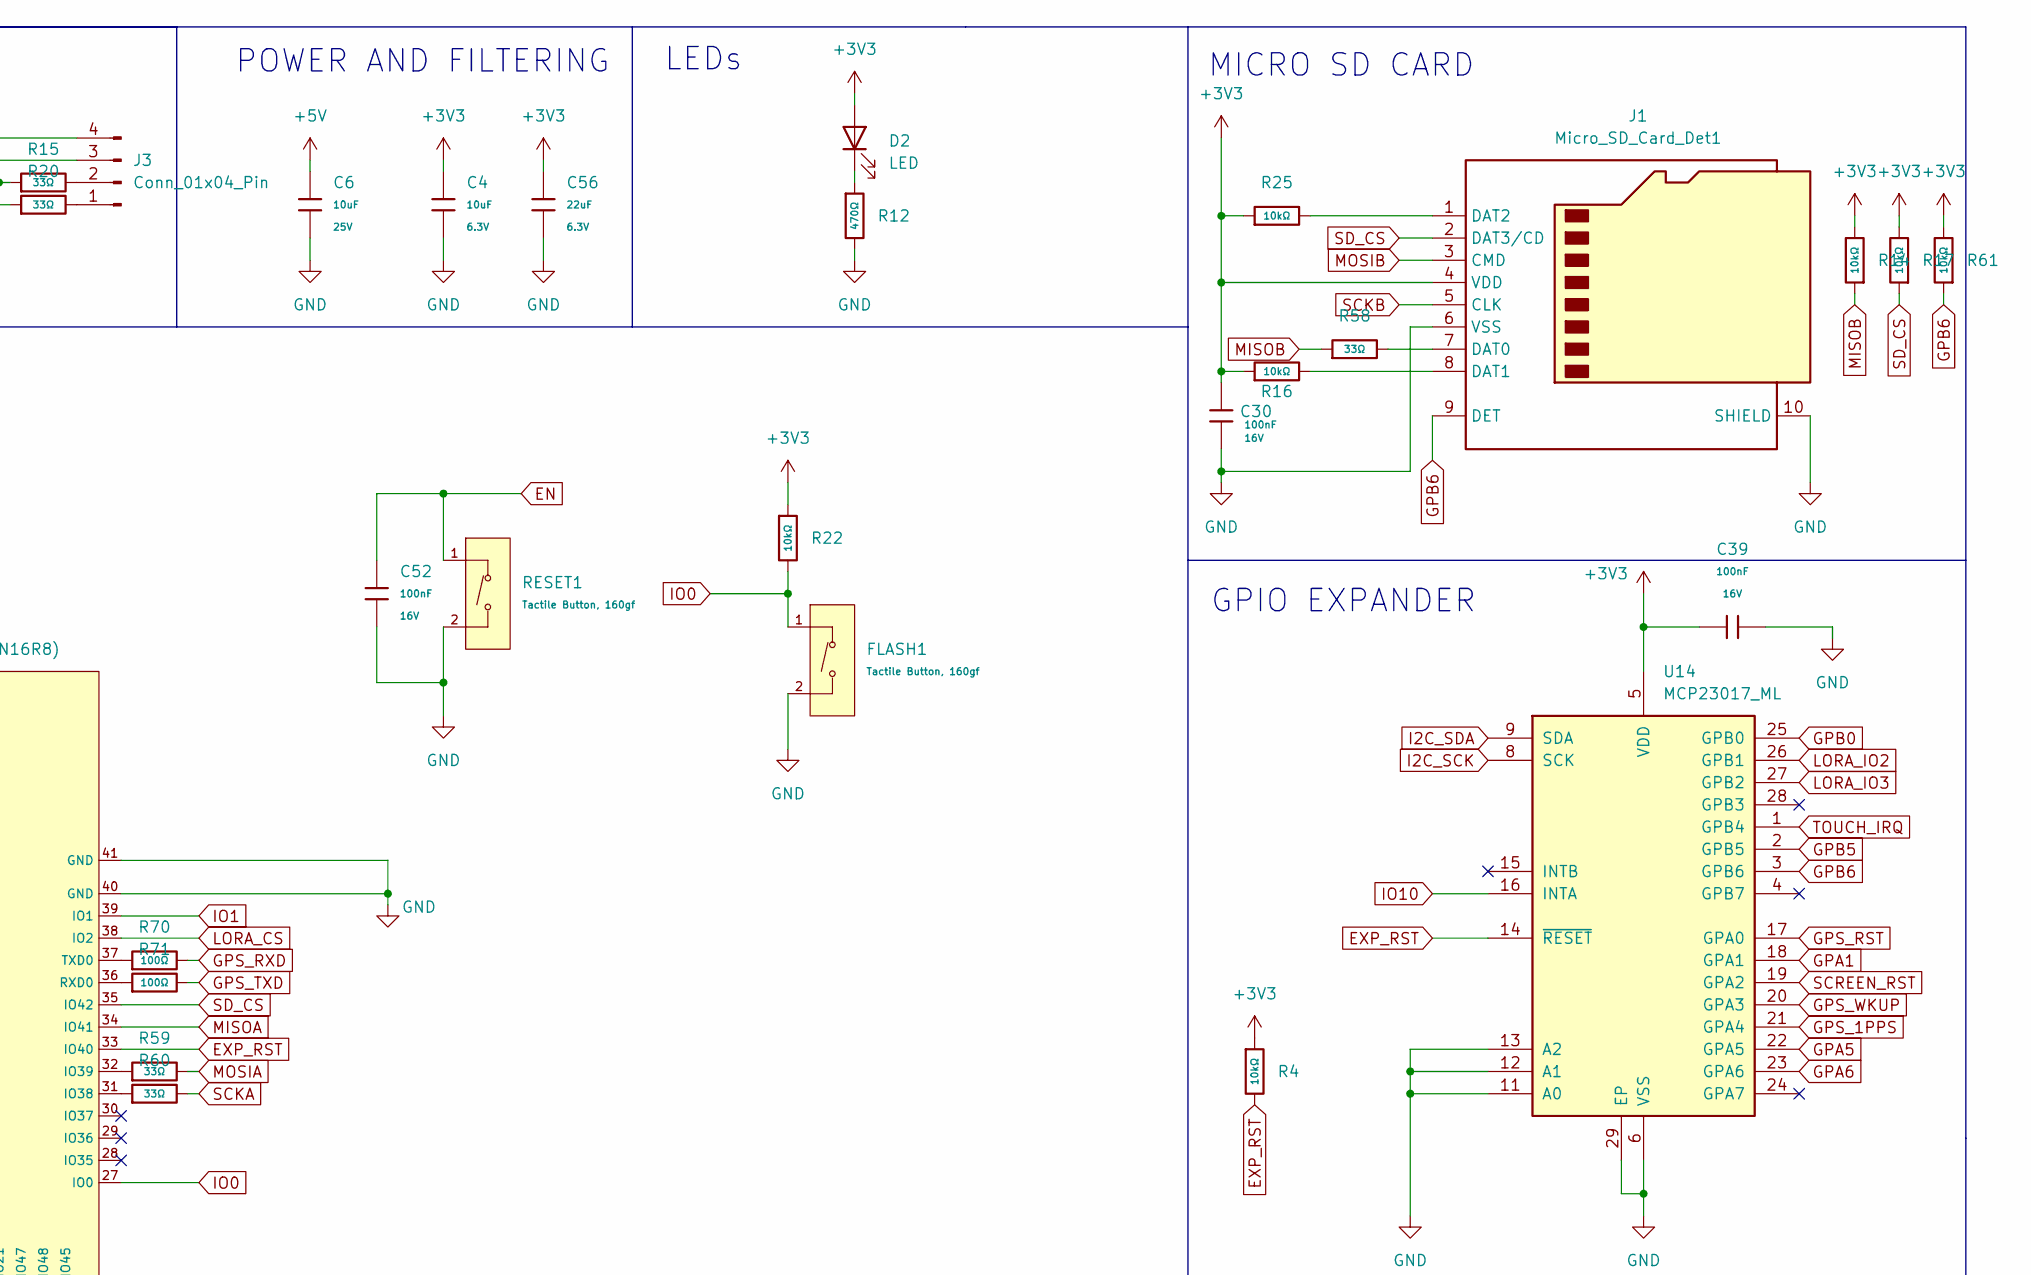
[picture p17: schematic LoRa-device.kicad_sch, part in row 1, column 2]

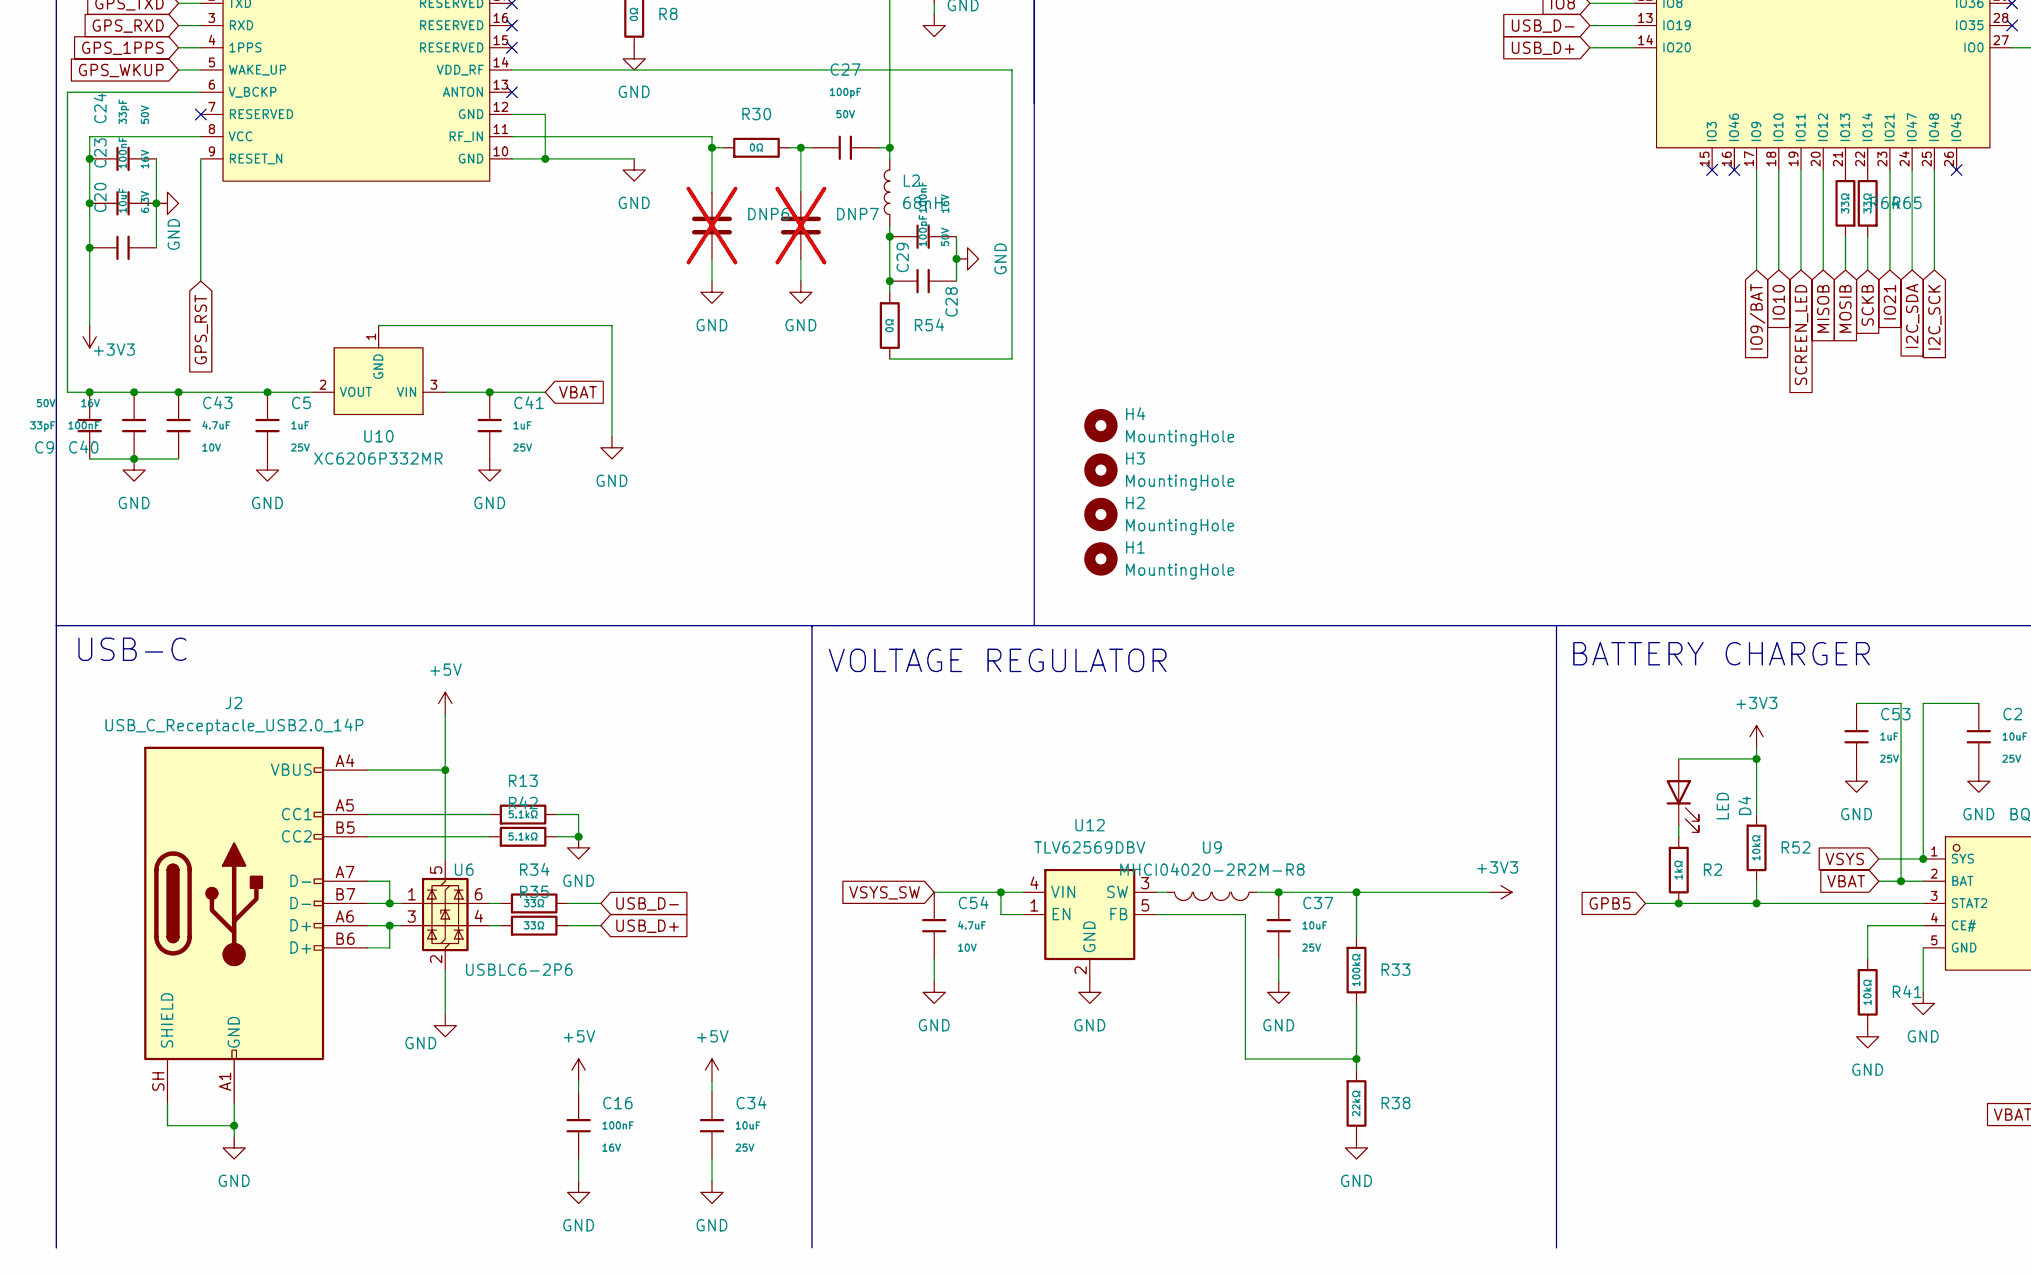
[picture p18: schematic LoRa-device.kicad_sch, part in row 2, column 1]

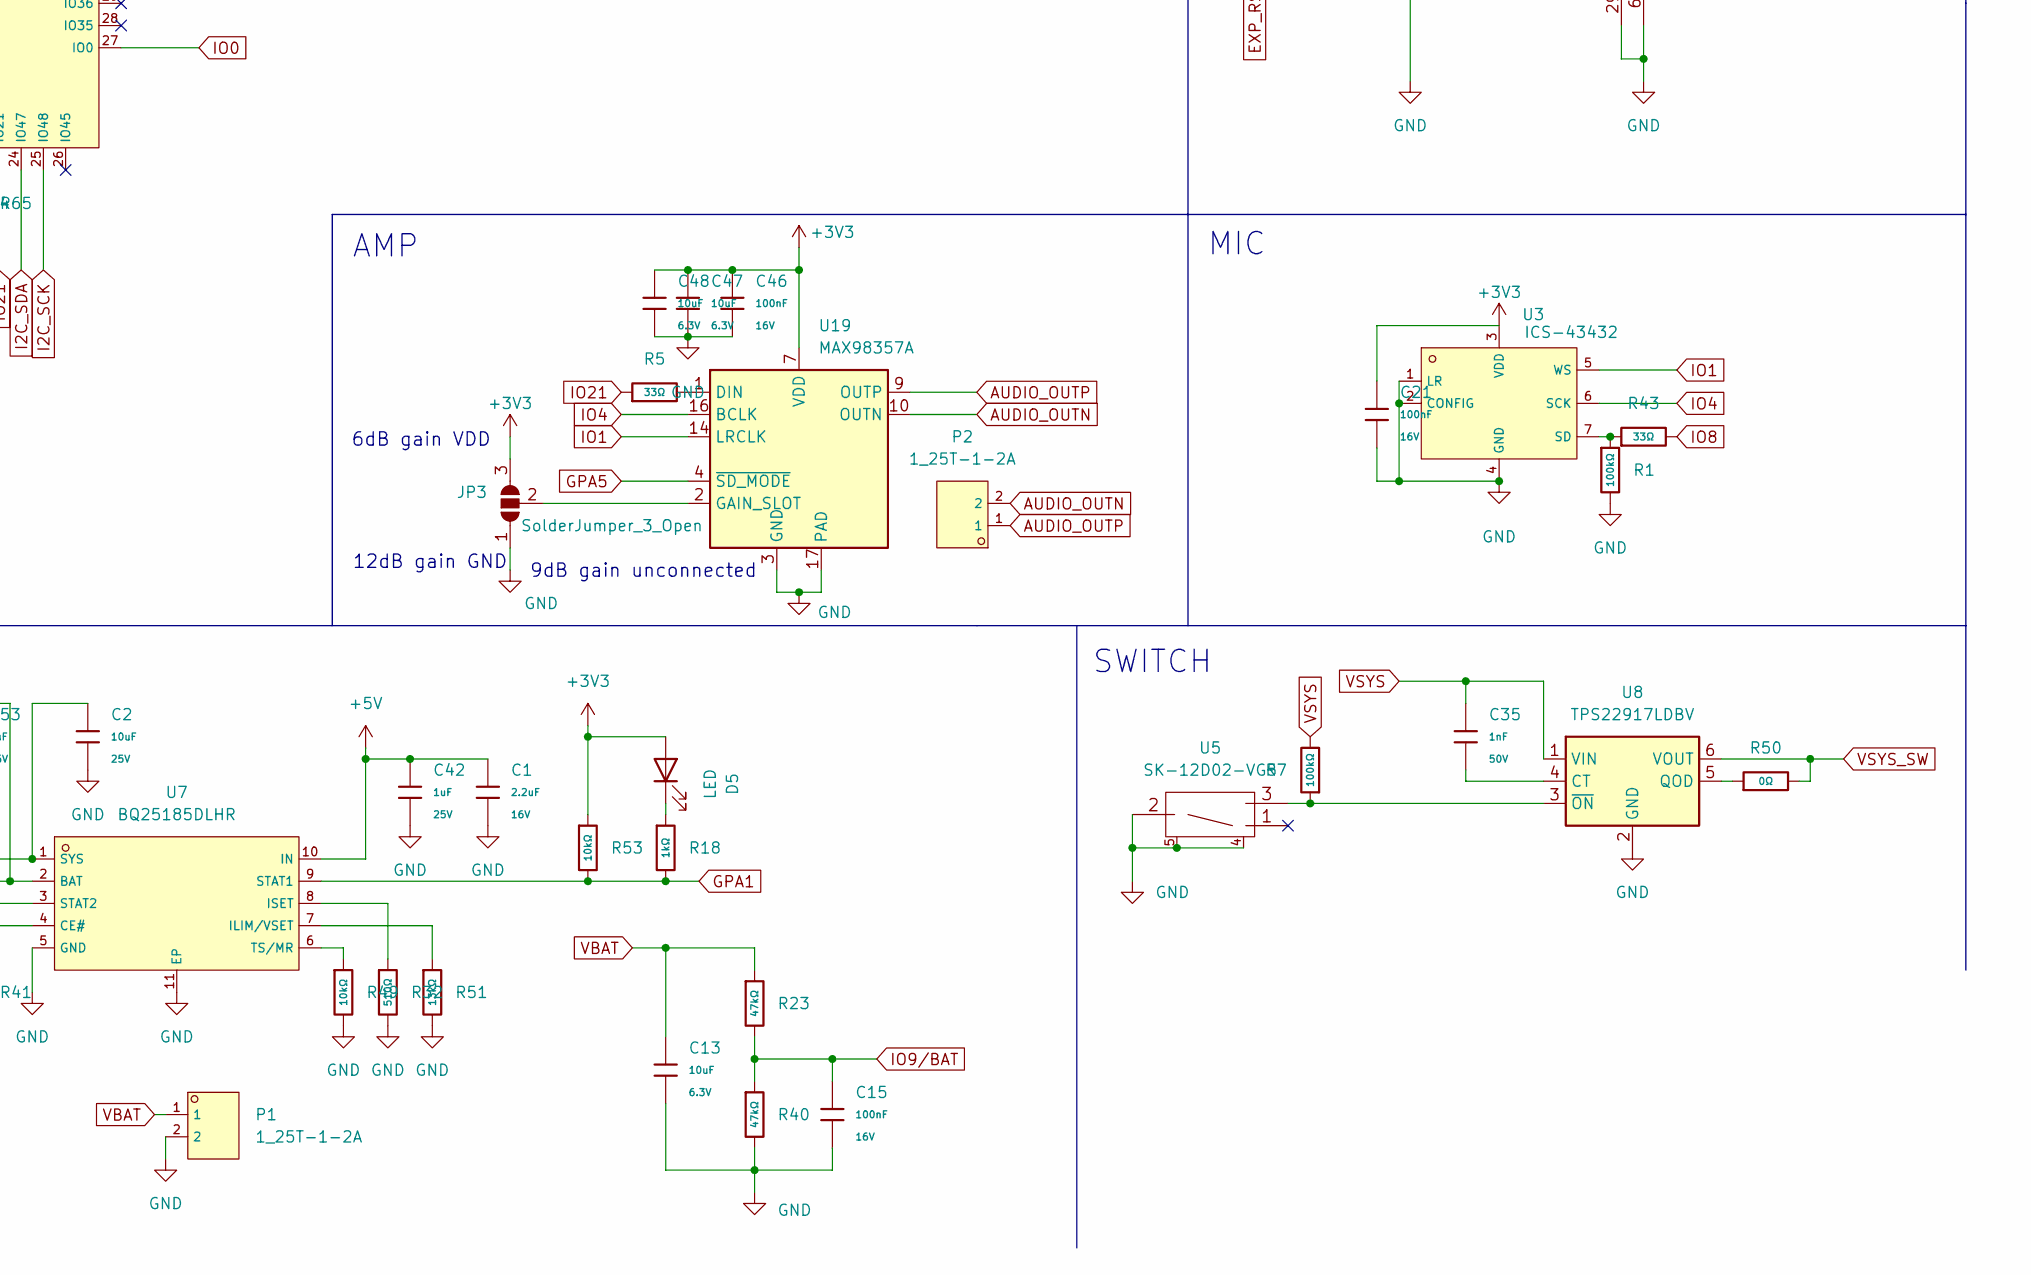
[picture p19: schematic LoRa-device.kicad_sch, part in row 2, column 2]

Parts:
C1: 2.2uF; C_0603; Voltage Rated 16V; Tolerance ±10%; Part CL10A225KO8NNNC; LCSC C23630
C2, C6, C34, C37: 10uF; C_0603; Voltage Rated 25V; Tolerance ±20%; Part CL10A106MA8NRNC; LCSC C96446
C4, C7, C13, C20, C47, C48: 10uF; C_0402; Voltage Rated 6.3V; Tolerance ±20%; Part CL05A106MQ5NUNC; LCSC C15525
C5, C19, C41, C42, C45, C53, C57: 1uF; C_0402; Voltage Rated 25V; Tolerance ±10%; Part CL05A105KA5NQNC; LCSC C52923
C8: 10nF; C_0402; Voltage Rated 50V; Tolerance ±10%; Part CL05B103KB5NNNC; LCSC C15195
C9, C24: 33pF; C_0402; Voltage Rated 50V; Tolerance ±5%; Part 0402CG330J500NT; LCSC C1562
C15, C16, C21, C23, C29, C30, C36, C39, C40, C46, C50, C52: 100nF; C_0402; Voltage Rated 16V; Tolerance ±10%; Part CL05B104KO5NNNC; LCSC C1525
C27, C28: 100pF; C_0402; Voltage Rated 50V; Tolerance ±5%; Part 0402CG101J500NT; LCSC C1546
C35: 1nF; C_0402; Voltage Rated 50V; Tolerance ±10%; Part 0402B102K500NT; LCSC C1523
C43, C54: 4.7uF; C_0402; Voltage Rated 10V; Tolerance ±20%; Part CL05A475MP5NRNC; LCSC C23733
C44: 220pF; C_0402; Voltage Rated 50V; Tolerance ±10%; Part 0402B221K500NT; LCSC C1530
C51, C56: 22uF; C_0603; Voltage Rated 6.3V; Tolerance ±20%; Part CL10A226MQ8NRNC; LCSC C59461
D2, D4, D5: LED; LED_0603_1608Metric; Part KT-0603R; LCSC C2286
DNP2, DNP4, DNP6, DNP7: C_0402; not fitted
FLASH1: Tactile Button, 160gf; SW_TS-1088-AR02016; Voltage Rating (Dc) 12V; Part TS-1088-AR02016; LCSC C720477
H1, H2, H3, H4: MountingHole; MountingHole_3mm
J1: Micro_SD_Card_Det1; TF-SMD_TF-01A; Part TF-01A; LCSC C91145
J2: USB_C_Receptacle_USB2.0_14P; USB_C_Receptacle_HCTL_HC-TYPE-C-16P-01A; Part HC-TYPE-C-16P-3M2S; LCSC C19274016
J3, J6: Conn_01x04_Pin; PinSocket_1x04_P2.54mm_Vertical
J4: Conn_01x14_Pin; PinSocket_1x14_P2.54mm_Vertical
J8: U.FL; IPEX-SMD_BWIPX-1-001E; Part BWU.FL-IPEX1; LCSC C5137195
JP3: SolderJumper_3_Open; SolderJumper-3_P1.3mm_Open_RoundedPad1.0x1.5mm
L2: 68nH; L_0402; Part SDCL1005C68NJTDF; LCSC C32836
P1, P2: 1_25T-1-2A; CONN-TH_1.25T-1-2A; LCSC C10819
R1, R7, R33: 100kΩ; R_0402; Overload Voltage (Max) 50V; Tolerance ±1%; Part 0402WGF1003TCE; LCSC C25741
R2, R18: 1kΩ; R_0402; Overload Voltage (Max) 50V; Tolerance ±1%; Part 0402WGF1001TCE; LCSC C11702
R4, R11, R14, R16, R17, R22, R25, R31, R37, R41, R49, R52, R53, R61, R62, R63, R72: 10kΩ; R_0402; Overload Voltage (Max) 50V; Tolerance ±1%; Part 0402WGF1002TCE; LCSC C25744
R5, R15, R20, R34, R35, R43, R44, R45, R46, R55, R56, R57, R58, R59, R60, R64, R65: 33Ω; R_0402; Overload Voltage (Max) 50V; Tolerance ±1%; Part 0402WGF330JTCE; LCSC C25105
R8, R10, R30, R50, R54: 0Ω; R_0402; Overload Voltage (Max) 50V; Tolerance ±1%; Part 0402WGF0000TCE; LCSC C17168
R12: 470Ω; R_0402; Overload Voltage (Max) 50V; Tolerance ±1%; Part 0402WGF4700TCE; LCSC C25117
R13, R42: 5.1kΩ; R_0402; Overload Voltage (Max) 50V; Tolerance ±1%; Part 0402WGF5101TCE; LCSC C25905
R23, R40: 47kΩ; R_0402; Overload Voltage (Max) 50V; Tolerance ±1%; Part 0402WGF4702TCE; LCSC C25792
R32: 510Ω; R_0402; Overload Voltage (Max) 50V; Tolerance ±1%; Part 0402WGF5100TCE; LCSC C25123
R38: 22kΩ; R_0402; Overload Voltage (Max) 50V; Tolerance ±1%; Part 0402WGF2202TCE; LCSC C25768
R47, R48: 2.2kΩ; R_0402; Overload Voltage (Max) 50V; Tolerance ±1%; Part 0402WGF2201TCE; LCSC C25879
R51: 13kΩ; R_0603; Overload Voltage (Max) 75V; Tolerance ±1%; Part 0603WAF1302T5E; LCSC C22797
R70, R71: 100Ω; R_0402; Overload Voltage (Max) 50V; Tolerance ±1%; Part 0402WGF1000TCE; LCSC C25076
RESET1: Tactile Button, 160gf; SW_TS-1088-AR02016; Voltage Rating (Dc) 12V; Part TS-1088-AR02016; LCSC C720477
SW1, SW2: EVQPUC02K; SW-SMD_EVQPUD02K; Part EVQPUC02K; LCSC C79174
U3: ICS-43432; SENSOR-SMD_ICS-43432; Part ICS-43432; LCSC C574021
U4: ESP32-S3-WROOM-1(N16R8); WIRELM-SMD_ESP32-S3-WROOM-1; Part ESP32-S3-WROOM-1(N16R8); LCSC C2913202
U5: SK-12D02-VG5; SW-TH_SK-12D02-VG5; Part SK-12D02-VG5; LCSC C136722
U6: USBLC6-2P6; SOT-666; Part USBLC6-2P6; LCSC C15999
U7: BQ25185DLHR; WSON-10_L2.2-W2.0-P0.40-BL-EP_TI_DLH0010A; Part BQ25185DLHR; LCSC C19725033
U8: TPS22917LDBV; SOT-23-6; Part TPS22917LDBVR; LCSC C3235537
U9: MHCI04020-2R2M-R8; IND-SMD_L4.6-W4.1; Part MHCI04020-2R2M-R8; LCSC C142096
U10: XC6206P332MR; SOT-23-3_L2.9-W1.6-P1.90-LS2.8-BR; Output Voltage 3.3V; Dropout Voltage 680mV@(100mA); Part XC6206P332MR-G; LCSC C5446
U12: TLV62569DBV; SOT-23-5; Part TLV62569DBVR; LCSC C141836
U14: MCP23017_ML; QFN-28-1EP_6x6mm_P0.65mm_EP4.25x4.25mm; Part MCP23017T-E/ML; LCSC C629439
U15: HJ-SMA275; SMA-SMD_BWSMA-KE-P001; Part HJ-SMA275; LCSC C2693809
U17: RA-01SH-P; COMM-SMD_17P-L17.0-W16.0-P2.00_RA-01S-P; Part Ra-01SH-P; LCSC C42420049
U18: L76KB-A58; GPSM-SMD_18P-L10.1-W9.7-P1.10; Part L76KB-A58; LCSC C2916234
U19: MAX98357A; TQFN-16-1EP_3x3mm_P0.5mm_EP1.23x1.23mm; Part MAX98357AETE+T; LCSC C910544

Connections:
+5V: C1.1, C6.1, C16.1, C34.1, C42.1, J2.A4 (VBUS), J2.A9 (VBUS), J2.B4 (VBUS), J2.B9 (VBUS), U6.5 (VBUS), U7.10 (IN)
AUDIO_OUTN: P2.2, U19.10 (OUTN)
AUDIO_OUTP: P2.1, U19.9 (OUTP)
EN: C52.1, C57.1, R72.2, RESET1.1 (A), U4.3 (EN)
EXP_RST: R4.2, U4.33 (IO40), U14.14 (~RESET)
GND: C1.2, C2.2, C4.2, C5.2, C6.2, C7.2, C8.2, C9.1, C13.2, C15.2, C16.2, C19.2, C20.2, C21.2, C23.2, C24.2, C28.2, C29.2, C30.2, C34.2, C36.2, C37.2, C39.1, C40.1, C41.2, C42.2, C43.2, C44.2, C45.2, C46.2, C47.2, C48.2, C50.1, C51.2, C52.2, C53.2, C54.2, C56.2, C57.2, DNP2.2, DNP4.2, DNP6.2, DNP7.2, FLASH1.2 (B), J1.6 (VSS), J1.10 (SHIELD), J1.11 (SHIELD), J1.12 (SHIELD), J1.13 (SHIELD), J2.A1 (GND), J2.A12 (GND), J2.B1 (GND), J2.B12 (GND), J2.SH (SHIELD), J3.3, J4.2, J8.2 (Ext), J8.3 (Ext), JP3.1 (A), P1.2, R1.2, R8.2, R12.2, R13.2, R32.2, R38.2, R40.2, R41.2, R42.2, R49.2, R51.2, RESET1.2 (B), SW1.2, SW1.4, SW2.2, SW2.4, U3.1 (LR), U3.2 (CONFIG), U3.4 (GND), U4.1 (GND), U4.40 (GND), U4.41 (GND), U5.2, U5.4, U5.5, U6.2 (GND), U7.5 (GND), U7.11 (EP), U8.2 (GND), U10.1 (GND), U12.2 (GND), U14.6 (VSS), U14.11 (A0), U14.12 (A1), U14.13 (A2), U14.29 (EP), U15.1, U15.2, U15.3, U15.4, U17.2 (GND), U17.9 (GND), U17.16 (GND), U17.17 (GND), U18.1 (GND), U18.10 (GND), U18.12 (GND), U19.3 (GND), U19.11 (GND), U19.15 (GND), U19.17 (PAD)
GPA1: R18.2, R53.2, U7.9 (STAT1), U14.18 (GPA1)
GPA5: U14.22 (GPA5), U19.4 (~SD_MODE)
GPA6: SW1.3, U14.23 (GPA6)
GPB0: SW2.3, U14.25 (GPB0)
GPB5: R2.2, R52.2, U7.3 (STAT2), U14.2 (GPB5)
GPB6: J1.9 (DET), R61.1, U14.3 (GPB6)
GPS_1PPS: U14.21 (GPA4), U18.4 (1PPS)
GPS_RST: U14.17 (GPA0), U18.9 (RESET_N)
GPS_RXD: R70.2, U18.3 (RXD)
GPS_TXD: R71.2, U18.2 (TXD)
GPS_WKUP: U14.20 (GPA3), U18.5 (WAKE_UP)
I2C_SCK: R20.1, R48.2, U4.25 (IO48), U14.8 (SCK)
I2C_SDA: R15.1, R47.2, U4.24 (IO47), U14.9 (SDA)
IO0: FLASH1.1 (A), R22.2, U4.27 (IO0)
IO1: U3.5 (WS), U4.39 (IO1), U19.14 (LRCLK)
IO4: U3.6 (SCK), U4.4 (IO4), U19.16 (BCLK)
IO8: R43.2, U4.12 (IO8)
IO9/BAT: C15.1, R23.2, R40.1, U4.17 (IO9)
IO10: U4.18 (IO10), U14.16 (INTA)
IO21: R5.1, U4.23 (IO21)
LORA_BUSY: U4.7 (IO7), U17.10 (BUSY)
LORA_CS: R11.1, U4.38 (IO2), U17.15 (NSS)
LORA_IO1: R44.1, U4.5 (IO5)
LORA_IO2: R45.1, U14.26 (GPB1)
LORA_IO3: R46.1, U14.27 (GPB2)
LORA_RF_EN: U4.9 (IO16), U17.11 (RF_EN)
LORA_RST: R63.1, U4.10 (IO17), U17.4 (RESET)
MISOA: R55.1, R57.2, U4.34 (IO41)
MISOB: R14.1, R56.1, R58.1, U4.20 (IO12)
MOSIA: J4.12, R59.2, U17.14 (MOSI)
MOSIB: J1.3 (CMD), J4.6, R64.1
unnamed: C27.1, DNP7.1, R30.2
unnamed: C28.1, C29.1, L2.1, R54.1
unnamed: D2.1 (K), R12.1
unnamed: D4.1 (K), R2.1
unnamed: D5.1 (K), R18.1
unnamed: DNP4.1, R10.2, U15.5
unnamed: J1.7 (DAT0), R58.2
unnamed: J1.8 (DAT1), R16.2
unnamed: J1.1 (DAT2), R25.2
unnamed: J2.A5 (CC1), R13.1
unnamed: J2.B5 (CC2), R42.1
unnamed: J2.A6 (D+), J2.B6 (D+), U6.3 (I/O2)
unnamed: J2.A7 (D-), J2.B7 (D-), U6.1 (I/O1)
unnamed: J3.1, R20.2
unnamed: J3.2, R15.2
unnamed: J4.9, R56.2
unnamed: J4.13, R55.2
unnamed: C27.2, J8.1 (In), L2.2
unnamed: JP3.2 (C), U19.2 (GAIN_SLOT)
unnamed: R34.1, U6.6 (I/O1)
unnamed: R35.1, U6.4 (I/O2)
unnamed: R1.1, R43.1, U3.7 (SD)
unnamed: R64.2, U4.21 (IO13)
unnamed: R65.2, U4.22 (IO14)
unnamed: R60.1, U4.31 (IO38)
unnamed: R59.1, U4.32 (IO39)
unnamed: R71.1, U4.36 (RXD0)
unnamed: R70.1, U4.37 (TXD0)
unnamed: R41.1, U7.4 (CE#)
unnamed: R51.1, U7.7 (ILIM/VSET)
unnamed: R32.1, U7.8 (ISET)
unnamed: R49.1, U7.6 (TS/MR)
unnamed: C35.2, U8.4 (CT)
unnamed: R50.1, U8.5 (QOD)
unnamed: R7.1, U5.3, U8.3 (~ON)
unnamed: C5.1, C9.2, C40.2, C43.1, U10.2 (VOUT), U18.6 (V_BCKP)
unnamed: R33.2, R38.1, U12.5 (FB)
unnamed: U9.1, U12.3 (SW)
unnamed: DNP2.1, R10.1, U17.1 (ANT)
unnamed: R44.2, U17.6 (DIO1)
unnamed: R45.2, U17.7 (DIO2)
unnamed: R46.2, U17.8 (DIO3)
unnamed: R57.1, U17.13 (MISO)
unnamed: DNP6.1, R30.1, U18.11 (RF_IN)
unnamed: R8.1, U18.18 (SET)
unnamed: R54.2, U18.14 (VDD_RF)
unnamed: R5.2, U19.1 (DIN)
SCKA: J4.10, R60.2, U17.12 (SCK)
SCKB: J1.5 (CLK), J4.7, R65.1
SCREEN_CS: J4.3, R37.1, U4.11 (IO18)
SCREEN_DC: J4.5, U4.8 (IO15)
SCREEN_LED: J4.8, U4.19 (IO11)
SCREEN_RST: J4.4, R62.1, U14.19 (GPA2)
SD_CS: J1.2 (DAT3/CD), R17.1, U4.35 (IO42)
TOUCH_CS: J4.11, R31.1, U4.6 (IO6)
TOUCH_IRQ: J4.14, U14.1 (GPB4)
USB_D+: R35.2, U4.14 (IO20)
USB_D-: R34.2, U4.13 (IO19)
VBAT: C13.1, C41.1, C53.1, P1.1, R23.1, U7.2 (BAT), U10.3 (VIN)
VDD_CPU: C4.1, C7.1, C8.1, C19.1, C20.1, C21.1, C23.1, C24.1, C30.1, C36.1, C37.1, C39.2, C44.1, C45.1, C46.1, C47.1, C48.1, C50.2, C51.1, C56.1, D2.2 (A), D4.2 (A), D5.2 (A), J1.4 (VDD), J3.4, J4.1, JP3.3 (B), R4.1, R11.2, R14.2, R16.1, R17.2, R22.1, R25.1, R31.2, R33.1, R37.2, R47.1, R48.1, R52.1, R53.1, R61.2, R62.2, R63.2, R72.1, U3.3 (VDD), U4.2 (3V3), U9.2, U14.5 (VDD), U17.3 (3V3), U18.8 (VCC), U19.7 (VDD), U19.8 (VDD)
VSYS: C2.1, C35.1, R7.2, U7.1 (SYS), U8.1 (VIN)
VSYS_SW: C54.1, R50.2, U8.6 (VOUT), U12.1 (EN), U12.4 (VIN)

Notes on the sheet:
BATTERY CHARGER
VOLTAGE REGULATOR
MIC
LoRa MODULE
LEDs
MCU
HEADER
MICRO SD CARD
GPS MODULE
AMP
I2C HEADER
ILI9341
9dB gain unconnected
SWITCH
12dB gain GND
6dB gain VDD
POWER AND FILTERING
BUTTONS
USB-C
GPIO EXPANDER

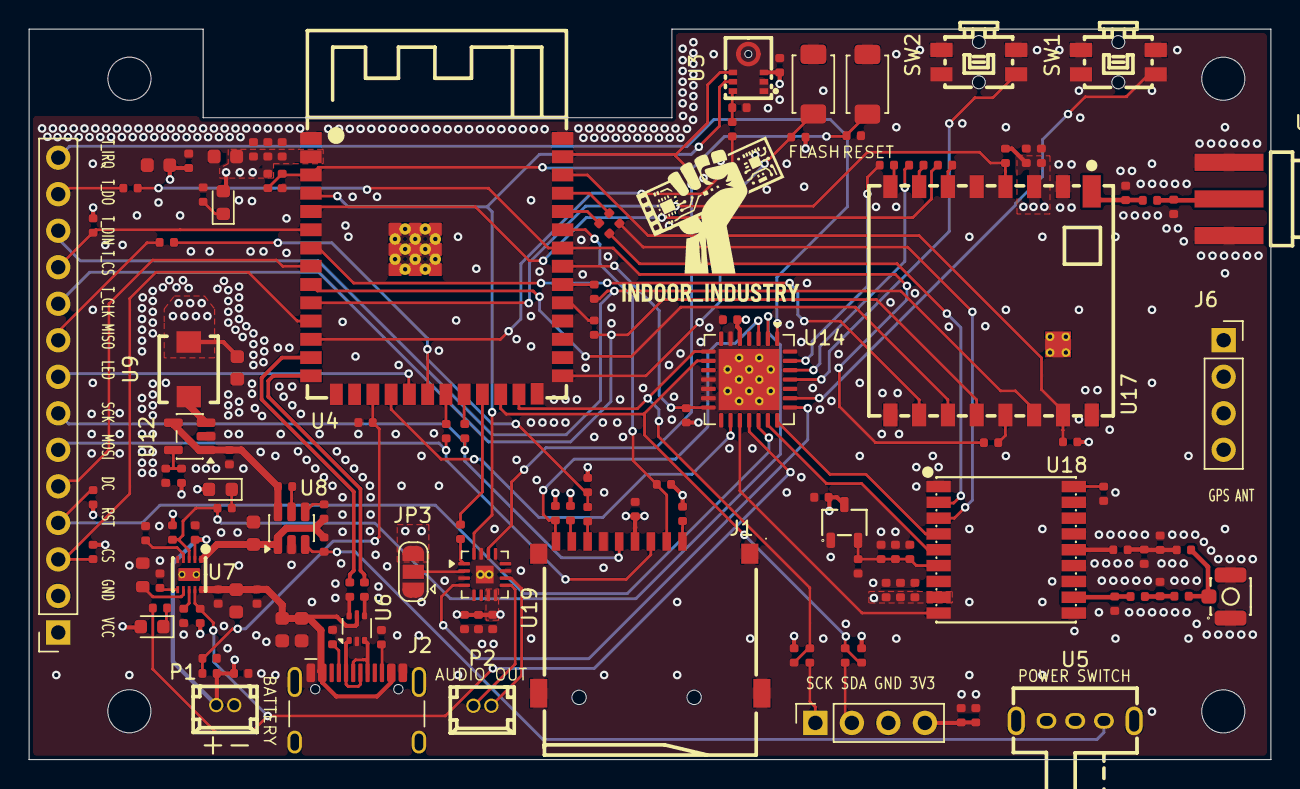
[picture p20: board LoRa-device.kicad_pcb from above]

Board: 4 copper layers, 86.4 x 50.8 mm, 136 parts (0 on the bottom side), 99 nets.

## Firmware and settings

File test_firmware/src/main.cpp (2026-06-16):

#include <Arduino.h>
#include <Wire.h>
#include <SPI.h>

#include "pins.h"
#include "config.h"
#include "mcp23017.h"
#include "display.h"
#include "touch.h"
#include "calibration.h"
#include "menu.h"
#include "board.h"
#include "test_sysinfo.h"
#include "test_battery.h"
#include "test_expander.h"
#include "test_touch.h"
#include "test_lora.h"
#include "test_sdcard.h"
#include "test_gps.h"
#include "test_audio_mic.h"
#include "test_audio_speaker.h"
#include "test_wifi_ble.h"
#include "test_backlight.h"
#include "test_calibration.h"
#include "volume.h"

MCP23017 mcp(Wire, MCP_I2C_ADDR);
unsigned long g_gpsBootMs = 0;

void setup() {
    Serial.begin(115200);
    Serial.println("[boot] LoRa test firmware starting");

    // Bring the MCP23017 out of its hardware reset before talking to it.
    pinMode(PIN_MCP_RST, OUTPUT);
    digitalWrite(PIN_MCP_RST, LOW);
    delay(10);
    digitalWrite(PIN_MCP_RST, HIGH);
    delay(10);

    Wire.begin(PIN_I2C_SDA, PIN_I2C_SCL);
    Wire.setClock(I2C_FREQ);
    if (!mcp.begin()) {
        Serial.println("WARNING: MCP23017 not responding on I2C bus");
    }

    Display::begin(mcp);
    Volume::begin();

    // SPI-A (touch + LoRa) on the global SPI object; the display/SD bus
    // has its own dedicated SPI host (see USE_HSPI_PORT in platformio.ini).
    SPI.begin(PIN_SPIA_SCLK, PIN_SPIA_MISO, PIN_SPIA_MOSI, -1);
    Touch::begin();

    // Holding SW1 during reset forces a fresh calibration even if valid
    // data is already stored in NVS - this is the escape hatch for when
    // stored calibration is bad and touch can't reach the menu's
    // "Recalibrate Touch" entry.
    bool forceCalib = !MCP23017::gpioBit(mcp.readGPIO(), MCP_BIT_SW1);
    if (!Calibration::load() || forceCalib) {
        Calibration::run();
    }

    // Wake the L76K GPS from standby (GPS_WKUP) and bring it out of
    // reset, then leave its UART open for the rest of the firmware's
    // life. The module is V_BCKP-backed for hot starts and must keep
    // running continuously - re-doing this every time the GPS test
    // screen opened was resetting the module before it could acquire a
    // fix.
    mcp.writePin(MCP_BIT_GPS_WKUP, true);
    mcp.writePin(MCP_BIT_GPS_RST, false);
    delay(100);
    mcp.writePin(MCP_BIT_GPS_RST, true);
    delay(1000); // let the module boot before we start reading its UART
    Serial1.setRxBufferSize(512);
    Serial1.begin(GPS_BAUD, SERIAL_8N1, PIN_GPS_RX, PIN_GPS_TX);
    g_gpsBootMs = millis();

    Menu::registerTest("System Info", testSysInfo);
    Menu::registerTest("Battery", testBattery);
    Menu::registerTest("I/O Expander", testExpander);
    Menu::registerTest("Touch Test", testTouch);
    Menu::registerTest("LoRa", testLora);
    Menu::registerTest("microSD", testSdCard);
    Menu::registerTest("GPS", testGps);
    Menu::registerTest("Microphone", testAudioMic);
    Menu::registerTest("Speaker", testAudioSpeaker);
    Menu::registerTest("WiFi / BLE", testWifiBle);
    Menu::registerTest("Backlight", testBacklight);
    Menu::registerTest("Recalibrate Touch", testRecalibrate);

    Menu::begin();
}

void loop() {
    Menu::loop();
}

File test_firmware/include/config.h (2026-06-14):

#pragma once

#include <Arduino.h>

// ---------------------------------------------------------------------
// SPI bus frequencies
// ---------------------------------------------------------------------
#define SPI_FREQ_SD     25000000
#define SPI_FREQ_LORA   2000000
#define SPI_FREQ_TOUCH  2000000

// ---------------------------------------------------------------------
// I2C
// ---------------------------------------------------------------------
#define I2C_FREQ        400000

// ---------------------------------------------------------------------
// LoRa radio defaults (RA-01SH-P / SX1262, 868MHz EU ISM)
// ---------------------------------------------------------------------
#define LORA_FREQ_MHZ       868.0f
#define LORA_BANDWIDTH_KHZ  125.0f
#define LORA_SPREADING      9
#define LORA_CODING_RATE    7
#define LORA_SYNC_WORD      0x12
#define LORA_TX_POWER_DBM   17
#define LORA_PREAMBLE_LEN   8

// ---------------------------------------------------------------------
// GPS UART
// ---------------------------------------------------------------------
#define GPS_BAUD        9600

// ---------------------------------------------------------------------
// Preferences (NVS) namespaces / keys
// ---------------------------------------------------------------------
// 3-point affine calibration: screenX = xa*rawX + xb*rawY + xc
//                              screenY = ya*rawX + yb*rawY + yc
// (handles axis swap/inversion, not just scale/offset)
// Namespace bumped to "touchcal2" because the calibration model changed
// from 2-point scale/offset to a 3-point affine fit (different NVS keys).
#define NVS_NS_TOUCHCAL     "touchcal2"
#define NVS_KEY_CAL_VALID   "valid"
#define NVS_KEY_CAL_XA      "xa"
#define NVS_KEY_CAL_XB      "xb"
#define NVS_KEY_CAL_XC      "xc"
#define NVS_KEY_CAL_YA      "ya"
#define NVS_KEY_CAL_YB      "yb"
#define NVS_KEY_CAL_YC      "yc"

// Backlight brightness (5-100%), persisted across reboots.
#define NVS_NS_DISPLAY      "display"
#define NVS_KEY_BL_PERCENT  "bl"

// Volume level (0-10), persisted across reboots.
#define NVS_NS_VOLUME       "volume"
#define NVS_KEY_VOL_LEVEL   "level"

// ---------------------------------------------------------------------
// UI colors (RGB565)
// ---------------------------------------------------------------------
#define COL_BG          0x0000  // black
#define COL_FG          0xFFFF  // white
#define COL_HEADER_BG   0x10A2  // dark blue
#define COL_ACCENT      0x07FF  // cyan
#define COL_OK          0x07E0  // green
#define COL_WARN        0xFFE0  // yellow
#define COL_ERR         0xF800  // red
#define COL_DIM         0x7BEF  // grey
#define COL_HILITE      0x39C7  // selection highlight (dark grey-blue)

// ---------------------------------------------------------------------
// UI layout
// ---------------------------------------------------------------------
#define HDR_H           28      // header bar height
#define MENU_ROW_H      26      // menu row height
#define STATUS_BAR_H    20      // bottom status bar height

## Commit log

2026-03-16 Major overhaul of version A
    [2985-6038.STEP, LoRa-device.FCStd, LoRa-device.kicad_pcb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]
2026-03-17 Just a backup.
    [LoRa-device.kicad_pcb, LoRa-device.kicad_sch, bom.csv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]
2026-03-26 Cleanup and update project files.
    [LoRa-device.FCStd, LoRa-device.kicad_pcb, LoRa-device.kicad_sch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]
2026-03-30 Backing up.
    [BOM-LoRa-device.csv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]
2026-03-31 To be routed, most work likely done.
    [311-99-104-41-001000 female.STEP, 311-99-114-41-001000 female.STEP, AUDIO-TH_320B.step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]
2026-04-03 new case design.
    [LoRa-device.FCStd, LoRa-device.kicad_pcb, LoRa-device.kicad_sch]
2026-04-06 Changed problematic components, updated case
    [LoRa-device.FCStd, LoRa-device.kicad_pcb, LoRa-device.kicad_sch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]
2026-04-08 Added buttons to case, rehauled power supply.
    [LoRa-device.FCStd, LoRa-device.kicad_pcb, LoRa-device.kicad_sch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]
2026-04-09 Almost ready for routing, major fixes, case ready.
    [BOM-LoRa-device.csv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]
2026-04-13 Case prototype ready. Added thermal pads.
    [BOM-LoRa-device.csv, LoRa-device-Bottom.step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]
2026-04-14 Ready for routing!
    [BOM-LoRa-device.csv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]
2026-04-15 Minor layout changes
    [LoRa-device.kicad_pcb]
2026-04-16 Routing started
    [LoRa-device.kicad_pcb, LoRa-device.kicad_sch]
2026-04-17 More routing, modifying case buttons and locking
    [LoRa-device.FCStd, LoRa-device.kicad_pcb, LoRa-device.kicad_sch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]
2026-04-20 Modified case and progressed routing
    [LoRa-device.FCStd, LoRa-device.kicad_pcb]
2026-04-24 Solved DRCs, updated case model
    [LoRa-device-Bottom.step, LoRa-device-Buttons.step, LoRa-device-Lid.step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]
2026-04-26 Minor component changes.
    [BOM-LoRa-device.csv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]
2026-04-29 Perfected 3V3 routing
    [LoRa-device.kicad_pcb, LoRa-device.kicad_sch]
2026-05-03 Production ready prototype
    [BOM-LoRa-device.csv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]
2026-05-10 Added version with module for easier cert
    [BOM-LoRa-device.csv, LoRa-device-Bottom.step, LoRa-device-Buttons.step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]
2026-05-11 Revised production ready bare chip and module ver.
    [BOM-LoRa-device.csv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]
2026-05-14 This version has been sent to production.
    [BOM-LoRa-device.csv, LoRa-device-Bottom.step, LoRa-device-Buttons.step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]
2026-06-10 First peripheral test firmware
    [T-3Y4W893083A-5units-BOM_LoRa-device.kicad_pcb(2026-05-14).xls]
2026-06-14 test_firmware works clean
    [partitions.csv]
2026-06-16 Serial monitor now works. Custom board defined.
    [partitions.csv]
